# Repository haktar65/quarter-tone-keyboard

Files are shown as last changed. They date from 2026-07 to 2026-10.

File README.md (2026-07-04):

# Quarter-Tone Keyboard (QTKB)

A professional, stage-ready 24-tone-per-octave MIDI keyboard instrument with a custom quarter-tone layout, custom sensing, and a newly active synthesizer / semi-weighted action direction.

Public shorthand for GitHub-facing material: `QTKB`.

## Current Direction

- Layout: Kassel Principle with `61` standard keys + `61` quarter-tone keys
- Active feel target: Access Virus C / Fatar-family synth action feel
- Active mechanical category: synthesizer / semi-weighted with integrated aftertouch
- Sensors: one Hall sensor per key
- Phase 1: MIDI input device with USB-MIDI and 5-pin DIN

## Documentation Map

- `docs/Research.md`: active concept and design rationale
- `docs/BuildGuide.md`: active geometry, build, and prototyping document
- `docs/archive/SteinwayLike/`: archived piano-like intermediate branch, including former `Research.md`, `BuildGuide.md`, and MP5 reference notes
- `docs/CAD/`: OpenSCAD models and milestone geometry files

## Working Method

This repository is maintained so that design work can continue across fresh checkouts and new VS Code sessions without reconstructing context from scratch.

Operational rules:

- active design decisions belong in `docs/Research.md`
- active geometry, prototype rules, and build-facing tables belong in `docs/BuildGuide.md`
- public project framing and naming belong in `README.md`
- historical branches stay under `docs/archive/` and are used as evidence, not as the active default
- when terminology changes, active documents are updated first and archive material gets explicit mapping notes where needed

## AI Collaboration In VS Code

The project is developed with AI assistance inside VS Code.

Current collaboration pattern:

- the AI first reloads repository instructions and active documents before making design proposals
- active source priority is: `.github/copilot-instructions.md`, `README.md`, `docs/Research.md`, `docs/BuildGuide.md`, then relevant archive files only if needed
- geometry decisions are expected to be carried in OpenSCAD files under `docs/CAD/` when practical
- chat discussion should follow the language of the user's prompts, while repository documentation is kept in English
- when a decision changes, the AI is expected to update the relevant repository documents so later sessions inherit the result

Typical startup summary for a fresh session:

- project shorthand: `QTKB`
- active branch: synth / semi-weighted
- feel reference: Access Virus C / Fatar-style synth action
- layout principle: Kassel
- scope: `122` keys total
- active key families: `MWT`, `MST`, `QWT`, `QST`

## Active Technical Direction

The active workstream no longer uses the previously explored deep piano-like geometry as its target mechanism.

Current focus:

- shallower synth-action packaging
- integrated aftertouch as a first-class design feature
- consistent semi-weighted feel across all `122` keys
- quarter-tone integration without inheriting hammer-action geometry penalties

## Preserved Decisions

These decisions remain active across the branch change:

- quarter-tone layout based on the Kassel Principle
- Hall sensor sensing concept
- Teensy-based real-time front-end architecture
- stage-ready control concept including pitch bend and expression controls
- custom mechanical implementation rather than direct reuse of a stock 12-tone keybed

## Status

- [x] Kassel layout selected
- [x] Hall sensor concept selected
- [x] Archived the earlier `Steinway-like` branch under `docs/archive/SteinwayLike/`
- [x] Switched active direction to synth / semi-weighted action
- [ ] Geometrically lay out the active `MT` and `QT` keyboard families
- [ ] Build a one-octave test stand after the current `MT` / `QT` geometry pass

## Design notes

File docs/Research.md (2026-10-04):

# Quarter-Tone Keyboard (QTKB) – Research & Concept

## Project Goal

Build a high-quality, stage-ready quarter-tone keyboard as a MIDI input device for a professional player.

Public shorthand for GitHub-facing material: `QTKB`.

Fixed top-level goals:

- quarter-tone grid with `24` tones per octave
- high-quality, repeatable playing feel
- stage-ready controls and robust hardware
- custom mechanics, sensing, electronics, and firmware

## Current Mechanical Direction

Update June 2026: the active target category is now a synthesizer / semi-weighted action with integrated aftertouch.

Primary feel reference:

- Access Virus C
- Fatar-family synth keyboard feel

This replaces the previously explored deeper piano-like intermediate branch as the active target mechanism.

## Pianist-Critical Requirements

The following remain decisive for the active branch:

- professional appearance and tactile quality
- reliable touch distinction between main keys and quarter-tone keys
- controlled, musically usable aftertouch
- consistent response across the full keyboard
- no cheap controller feel

The active branch no longer optimizes around hammer-action-like proportions.

## Fixed Decisions That Remain Active

The branch change does not affect these decisions:

- layout principle: Kassel Principle
- scope: `61` main keys plus `61` quarter-tone keys
- key sensing: one Hall sensor per key
- aftertouch principle: travel into an elastomeric stop rather than FSR-based force sensing
- firmware split: real-time sensor front-end plus higher-level protocol/control layer
- stage focus: USB-MIDI, 5-pin DIN, performance controllers

## Mechanical Consequences of the New Direction

The active synth / semi-weighted branch implies:

- shallower action depth than the archived piano-like branch
- lower moving mass and less emphasis on long piano-style front lever arms
- a compact `MWT` planform with `50 mm` head length, `2 mm` lip, and `35 mm` tail length; the detailed, parameterized layout is held in `docs/CAD/Design/MasterLayout.csv`
- aftertouch must be designed into the base mechanism from the start
- pivot, travel, and return-force geometry must be re-derived from the synth-action category, not reused from the archived branch
- QT integration should be solved against the lighter action family, not against a deep hammer-style package

## Open Geometry Questions for the Active Branch

The following items now define the active research backlog:

- exact Access Virus C keybed family / concrete Fatar reference if identifiable
- main-key travel target for the synth branch
- black-key travel target for the synth branch
- pivot position and effective lever arms for a synth-like mechanism
- required pivot-axle capture in lever direction; the first print suggests the current wrap is too small, so a roughly `180 deg` capture should be tested as an active candidate where spacer washers already retain the axle laterally
- whether reducing the lever-side pivot support land to `5 mm` in the local washer zone remains mechanically acceptable inside the available `6.84 mm` width when that local contact region is executed in Tough Resin
- aftertouch onset travel, reserve travel, and target force range
- how the quarter-tone rows should be coupled to the shallower main-key geometry
- Hall sensor placement for the new shallower package

## Active Zero-Stop Guide Direction

Update September 2026: reject the radial splint / PTFE-tube guide near the
aftertouch buffer. The small-radius, family-specific bent splints make the
reaction-group construction unnecessarily difficult. The active prototype
instead uses the pivot axis and a guide at the rear zero stop as two separated
points of lateral `X` guidance.

- retain the shared pivot axis as the front guidance point
- place the brass guide splint and its PTFE guide at the rear zero-stop
	structure, about `75 mm` behind the pivot; it must be mechanically separate
	from the hard zero-stop contact function
- move the key's zero-stop lip slightly forward of the splint / guide line so
	the lip reaches its unobstructed stop face without interference from either
	the splint or the PTFE guide package

- use `5 x 4 mm` PTFE tube, compressed externally to an approximately
	`4 mm` in `X` by `6 mm` in `Y` oval section. The larger `Y` compliance accommodates the small
	kinematic migration at the rear guide while the narrow `X` direction provides
	lateral location
- use a `10 mm` axial PTFE bearing length as the first prototype value. It is
	intended for lateral control with the pivot as the second bearing point, not
	as a torsional bearing about `Y`
- keep the PTFE tube vertical in global `Z`. Tilt the straight brass splint
	by `4 deg` in its local `YZ` plane so it is approximately parallel to the
	tube around the middle of the QST stroke; the resulting endpoint mismatch is
	about `+/-3.6 deg` for the `7.17 deg` QST full-aftertouch rotation
- use a rounded and polished brass splint with `25 mm` free working length.
	At the QST governing case, a rear guide `75 mm` behind the pivot moves about
	`9.4 mm` in `Z` and `0.59 mm` in `Y` at `7.2 deg` full aftertouch. The
	`25 mm` free length preserves the `10 mm` PTFE engagement through that stroke
	with a practical end reserve; do not reduce it to `22 mm` until actual
	travel, tube deformation, and assembly tolerances are measured
- do not claim that this guide controls rotation about `Y`; validate remaining
	torsional freedom at the pivot and rear guide in the physical prototype

The first fabrication method is a straight, `4 deg`-tilted brass splint in a
printed rear guide block with a vertical PTFE tube. No radius-specific forming
jig is required. Prototype the oval PTFE section for friction, wear, `X` play,
and its actual available `Y` compliance before propagating the package across
all key families.

### Optional Aftertouch Stamp Catch Guide

An optional passive secondary guide may surround the key-side aftertouch stamp
with a shallow fixed tray. It is not part of the normal guiding system: pivot
and rear zero-stop guide remain authoritative.

- keep more than `0.5 mm` radial clearance around the stamp, so it remains
	non-contact in normal playing and normal aftertouch
- use only `4-6 mm` first-pass capture height, with generous lead-in radii and
	rounded stamp edges; do not turn it into a long sliding bearing
- its purpose is to catch exceptional side load from glissando or wide playing
	spans before the stamp is forced substantially sideways
- validate under full aftertouch and side load that first contact does not
	appreciably alter vertical end position, aftertouch force, or Hall signal

## Active Aftertouch Reaction Direction

Update August 2026: arrange the fixed reaction group horizontally in global
`XY` at the full-aftertouch position. The key-side stamp or contact face is
intentionally angled relative to the local key surface so that its face is also
horizontal at full aftertouch.

- the full-aftertouch reaction acts predominantly in global `Z`, rather than
	introducing a systematic `Y` component into the pivot and guide splint
- normal-travel to full-aftertouch motion produces only a small controlled
	tangential displacement in the felt contact layer; current first-pass values
	are about `0.10 mm` (`MWT`), `0.12 mm` (`MST`), `0.16-0.36 mm` (`QWT`), and
	`0.21-0.40 mm` (`QST`)
- use a smooth, continuous, limited-area contact face rather than a broad
	clamping interface; the felt absorbs the residual angle and displacement
- for FDM prototype stamps, print upright with the load-bearing contact face
	horizontal and uppermost. The vertical reaction load then acts principally
	in compression through the layer stack, and no support touches the functional
	contact face

## Electronics and Firmware Direction

The action-family switch does not change the preferred electronics architecture:

- Teensy remains the real-time sensor front-end
- Hall sensors remain the key-position sensing basis
- selected Hall sensor: `Allegro A1324LUA-T`, a linear ratiometric analog Hall sensor in the `TO-92S` package; use one sensor per key
- use the continuous analog position signal for velocity threshold timing and aftertouch evaluation
- multiplexed analog acquisition remains acceptable
- optional second processor / protocol back-end remains open

## Active Multiplexed Scan and Decoupling Direction

Update September 2026: the initial electronics prototype is a complete grouped
Hall-sensor front end, rather than a single sensor on an ideal short connection.

- use `8 x CD74HC4067` analog multiplexers, each with one separate Teensy ADC
	input; the four mux address lines are shared, giving eight simultaneous values
	per address position and capacity for `128` inputs
- treat the eight mux outputs at a common address as an atomic acquisition
	block. Read block `n`, change the common address immediately to `n + 1`, then
	process or queue block `n` while the next block settles
- start with about `90 us` address settling. This is intentionally conservative
	and should cover the selected Hall output, harness, mux, and ADC acquisition
	path; raw ADC data determines whether it can be reduced
- do not add Hall-output capacitors initially. They are a dynamic signal filter
	and can worsen address-switch settling; they require a demonstrated noise
	benefit before becoming part of the design
- retain minimal group-level supply decoupling independently of the chosen mux
	settling time: `10 uF` at both physical ends of a group, plus `100 nF` at the
	mux/group supply injection and at the far end when the harness is long
- do not provision `100 nF` at every sensor initially. Add sensor-local parts
	only if a full-group test shows a local supply-noise mechanism which the
	group-level capacitors do not suppress
- acquire and transmit data asynchronously from the periodic scan. USB-MIDI,
	debug logs, and a future protocol back-end must consume buffered events rather
	than introduce timing jitter into address-block acquisition

The important distinction is between selected-channel signal settling and
supply-rail decoupling. A `90 us` wait may be more than sufficient for the
former, but does not by itself lower the local VCC/GND impedance during digital
switching or key motion. The first group test must compare `10`, `20`, `40`,
`60`, and `90 us` waits while recording raw rest noise, address residue,
repeatability, travel headroom, and supply ripple. This measurement, using the
intended cable length and scan load, decides both the final wait time and
whether additional ceramic capacitors are justified.

## Active Hall Crosstalk Assessment

Current working concern:

- the closest known intra-group Hall-sensor case is inside `QWT`, especially the `E/F` neighbor pair
- the current rough geometry uses cylindrical magnets `4 x 3 mm`
- the active own-magnet operating region is expected around `2-3 mm` from its own Hall sensor in the relevant near-contact region
- the same local pair can place a neighbor magnet at about `15 mm` lateral offset in `X`
- the rest position of a non-pressed neighboring key is currently assumed to keep its own magnet about `12-13 mm` above its own Hall sensor in `Z`

Current prototype observation (August 2026):

- in the tested sensor / magnet arrangement, a lateral `X` offset of `10 mm` produced no practically visible neighbor response; this is stronger evidence than the earlier conservative dipole estimate, but remains geometry-specific until confirmed in the final lever layout
- the observed useful own-magnet distance span is about `8 mm`; calibrate each key's rest value and full-travel value individually rather than requiring identical absolute sensor placement across all keys
- steel hardware near a sensor can redirect the own-magnet field and must not be treated as equivalent to a laterally offset neighbor magnet; brass remains preferred for the adjustable guide splints

First-order interpretation:

- the relevant magnetic coupling should be treated with a dipole-like first estimate, so field influence falls roughly with `1/r^3`, not with `1/r^2`
- for the actively pressed key, a `15 mm` lateral neighbor is therefore expected to be small compared with the own-magnet signal once the own magnet is only about `2-3 mm` from its own sensor
- for the non-pressed neighboring key, the situation is less favorable because the comparison is then no longer `2-3 mm` versus `15 mm`, but roughly `12-13 mm` versus `15 mm`
- this means a visible neighbor-induced offset in the idle or upper-stroke signal is plausible even if the main active stroke remains dominated by the own magnet

Current risk interpretation:

- the primary risk is not currently seen in the main stroke of the pressed key
- the more credible risk is crosstalk in the upper signal region of the non-pressed neighbor, and possibly in the later expression / aftertouch interpretation window
- if no activity is derived from the rest-near zone, crosstalk there is largely irrelevant from a musical-control perspective
- a moderate, systematic influence in the expression or aftertouch region is considered more acceptable than ambiguity in the main attack / velocity region

Current project interpretation:

- `QWT E/F` should be treated as the worst-case crosstalk pair for prototype verification
- the present expectation is that the main stroke may still remain usable without mechanical redesign even if the upper signal region shows measurable neighbor influence
- if the crosstalk is mostly systematic and appears mainly in expression / aftertouch, later compensation in signal processing remains a viable option
- compensation should only be considered after direct measurement of the worst-case pair; it should not be assumed as a substitute for first-order geometric sanity

## Active Zero-Stop Damping Decision

Update June 2026:

- the rear zero stop remains a hard geometric rest-height reference, not a soft free-working stop
- acoustic damping at the zero stop may be added, but only as a thin, strongly constrained working layer in front of a hard rail
- preferred first damping forms are a small solid profile or strip in `TPU` or `PORON`, not a hollow profile
- hollow profiles remain possible as acoustic experiments, but they are not the preferred reference-defining construction because they are more prone to hysteresis, temperature sensitivity, and rest-height drift
- shrink tube may still be used around separate trim-mass pieces as a pragmatic noise-reduction measure, but it should not be shrunk directly on the mounted `ASA` lever and should not define the zero-stop geometry

## Archive Boundary

The previously explored piano-like intermediate branch is now preserved only as an archive snapshot under:

- `docs/archive/SteinwayLike/Research.md`
- `docs/archive/SteinwayLike/BuildGuide.md`
- `docs/archive/SteinwayLike/MP5GeometryReference.md`
- `docs/archive/SteinwayLike/SteinwayLikeArchive.md`

Those files remain useful as historical design context, but they no longer define the active geometry target.

Historical archive terminology may still use earlier internal abbreviations.

## Immediate Next Steps

- identify the best usable Access Virus C / Fatar reference data
- define the active coordinate system for the synth branch
- establish first main-key synth geometry targets
- derive quarter-tone packaging rules from the new shallow action category
- test whether a roughly `180 deg` pivot wrap gives enough directional stiffness in the lever while remaining practical with the washer-retained axle concept
- test whether a local reduction of the lever-side pivot support land to `5 mm` in the washer zone is still stiff enough when printed in Tough Resin
- measure the `QWT E/F` Hall crosstalk worst case and separate main-stroke relevance from expression / aftertouch relevance before changing magnet polarity or local sensor topology
- build a single-key prototype around the synth-action assumptions

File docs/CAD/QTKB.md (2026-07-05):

# QTKB STEP Exports

The STEP files in this folder are currently direct exports from the active QTKB working drawing.

At this stage they should be treated as working geometry snapshots, not as a curated release set.
The source drawing still contains parallel design experiments, intermediate variants, and naming that reflects the current TurboCAD work structure rather than a final part taxonomy.
In particular, `QTKB.stp` should currently be expected to change substantially over time because it is the direct export of the active working map.

Because of that, the exported STEP files are intentionally not documented one by one yet.
Adding detailed per-file notes at this point would create documentation overhead without much long-term value.

Current meaning of the exported files:

- `QTKB.stp`: full export of the current working drawing; this file may change strongly and often because the underlying working map is still in active exploratory use
- `QTKB-blocks/`: per-block STEP exports generated from the same working drawing; these are also still provisional, but the individual block exports are expected to stabilize earlier than the full drawing export

Once the design stabilizes, the STEP exports will be cleaned up, grouped more deliberately, and documented individually.

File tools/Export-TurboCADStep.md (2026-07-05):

# Export-TurboCADStep.vbs

Small helper script for exporting one TurboCAD `.tcw` drawing and its blocks as STEP files.

## What it does

- opens the source `.tcw` through TurboCAD COM automation
- creates a temporary working copy inside `_tcw-temp`
- exports the full drawing as `<project>.stp`
- clears the working drawing, inserts one block, and exports that state as one STEP file per block
- writes block STEP files into `<project>-blocks`

## Requirements

- Windows
- TurboCAD 2020 installed locally
- TurboCAD COM automation available as `TurboCAD.Application`
- the source drawing should contain 3D geometry that TurboCAD can actually write to STEP

Pure 2D blocks may not produce useful STEP output.

## Usage

```cmd
cscript //nologo Export-TurboCADStep.vbs <input.tcw> <output-dir> [visible]
```

Example:

```cmd
cscript //nologo Export-TurboCADStep.vbs "C:\path\to\drawing.tcw" "C:\path\to\export" True
```

## Parameters

- `input.tcw`: source TurboCAD file
- `output-dir`: target folder for the exported STEP files
- `visible`: optional Boolean, usually `True` or `False`; default is `True`

## Output layout

```text
export/
├── <project>.stp
├── <project>-blocks/
│   ├── BlockA.stp
│   ├── BlockB.stp
│   └── ...
└── _tcw-temp/
    └── <project>-working-<timestamp>.tcw
```

## Current behavior

- the script aborts immediately if any `tcw27.exe` process is already running
- existing STEP files with the same name are overwritten
- block names are sanitized for Windows file names
- the script prints `Writing: ...` for each STEP file it exports
- the script attempts to delete the temporary working copy at the end

## Notes

- the block export path currently uses the block name in `AddBlockInsertion`
- runtime errors are intentionally not masked; VBScript should stop directly on the failing line
- after `SaveCopyAs`, the script still checks whether the STEP file was actually written

## First troubleshooting steps

- run once with `True` as the third argument so you can watch TurboCAD during the export
- if the script aborts on a specific line, use that exact VBScript line number as the primary debugging anchor
- test the same drawing manually in TurboCAD with a normal STEP export to confirm that the geometry is STEP-compatible

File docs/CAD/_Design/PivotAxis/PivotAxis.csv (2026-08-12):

Pivot Axis Parameters
LengthX	WidthY	MountHeight	BrassShaftRadius	WashersRadius	WashersThickness	K20Z
165.2	20	3	2	6	1	-20
Geometry Parameters
Outer Slope	Inner Slope	WT Width C-E	WT Width F-B	ST Width
10	40	14.6	13.475	13.5
Segmentation
C		C#		D		D#		E		F		F#		G		G#		A		A#		B
0	7.3	14.6	21.35	28.1	35.4	42.7	49.45	56.2	63.5	70.8	77.5375	84.275	91.025	97.775	104.512	111.25	118	124.75	131.488	138.225	144.975	151.725	158.463	165.2

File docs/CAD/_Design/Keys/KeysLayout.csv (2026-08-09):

Common Dimensions
Parameters	OctaveWidth	Air Gap X	Air Gap Y	Rounding	PivotAxisY	PivotAxisZ
	165.2	1	1	1	210	-12
Calculations
MWT Dimensions
Parameters	Head Length	Tail Length	Height	Lip Length	Lip Height
	50	35	14	2	2
Calculations	Head Width	Rear Width C-E	Read Width F-B	BackFaceSlop
	22.6	13.6	12.475	85.7108
MWT Keys Configuration Table
	Head Start X	Tail Start X	Tail Width
C	0	0	13.6
D	23.6	28.1	13.6
E	47.2	56.2	13.6
F	70.8	70.8	12.475
G	94.4	97.775	12.475
A	118	124.75	12.475
B	141.6	151.725	12.475
MST Dimensions
Parameters	Start Y	Length	Width	Key Height	Body Height	Top Slope	Side Bevel	Front Bevel
	51	64	12.5	12	10	1	2.38594	11.7683
Calculations	BackFaceSlop
	82.8008
MST Keys Configuration Table
	Start X
C#	14.6
D#	42.7
F#	84.275
G#	111.25
A#	138.225
QWT Dimensions
Parameters	Start Y	Length	Key Height	Body Height	Side Bevel	Front Bevel
	86	84	12	10	18.4349	14.0362
Calculations
QWT Keys Configuration Table
	Start X	Width
Cq	0	13.6
Dq	28.1	13.6
Eq	56.2	13.6
Fq	70.8	12.475
Gq	97.775	12.475
Aq	124.75	12.475
Bq	151.725	12.475
QST Dimensions
Parameters	Start Y	Length	Key Height	Body Height	Side Bevel	Front Bevel
	116	54	12	10	18.4349	14.0362
Calculations	Start Z
	11
QST Keys Configuration Table
	Start X	Width
C#q	14.6	12.5
D#q	42.7	12.5
F#q	84.275	12.5
G#q	111.25	12.5
A#q	138.225	12.5

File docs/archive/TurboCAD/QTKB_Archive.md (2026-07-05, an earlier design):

# QTKB Archived STEP Exports

The STEP files covered by this note are archive exports only.

They represent drawings and geometry snapshots that are no longer part of the active QTKB workstream, but may still be worth keeping for selective reuse, comparison, or extraction of isolated ideas.

These files should not be treated as active design defaults.
Active geometry and active branch decisions remain defined by:

- `docs/Research.md`
- `docs/BuildGuide.md`
- the current active CAD work under `QTKB.stp` and `QTKB-blocks/`

Current meaning of the archived files:

- `QTKB_Archive.stp`: full archived STEP export of drawings that are no longer needed in the active workstream
- `QTKB_Archive-blocks/`: archived per-block STEP exports kept only for possible later reuse of individual geometry fragments

Usage rule:

- reuse material from this archive deliberately, not implicitly
- when reusing geometry, re-check it against the current synth / semi-weighted branch assumptions before bringing it back into active CAD
- do not interpret archived naming, dimensions, or package logic as current defaults

This archive is intentionally retained as a parts and ideas reservoir, not as a maintained parallel design branch.

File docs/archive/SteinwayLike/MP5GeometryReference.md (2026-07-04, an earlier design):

# Kawai MP5 Geometry Reference

> **Archive role (June 2026):** This MP5 note now belongs to the archived `Steinway-like` branch. It remains useful as a proportional reference for the earlier piano-like geometry study, but it is no longer the active target direction for the keyboard layout.

This note collects the geometry-related information currently available for the Kawai MP5 and separates public source-backed facts from project-side geometric inference.

## 1. Publicly Confirmed MP5 Data

The following items could be confirmed from Kawai's public MP5 archive/specification material:

- Keyboard action: `88 weighted keys, Advanced Hammer Action IV-E with AR technology`
- Overall dimensions: `1356 x 340 x 172 mm` (`W x D x H`)
- Weight: `20.5 kg`

These are useful packaging anchors, but they do **not** include an internal pivot drawing or a service-level action section with exact key-axis coordinates.

## 2. Public Geometry That Could Not Be Confirmed Directly

The following internal action data has **not** been found in a public Kawai source during this research pass:

- exact white-key pivot coordinates relative to the front edge
- exact pivot height relative to the white-key top surface
- exact white-key overall length or hammer-stick length
- exact black-key reference point and black-key lever arm
- exact guide-pin or balance-pin coordinates
- exact MP5 service drawing for the AHA IV-E action

Therefore, any concrete pivot coordinate stated below must be treated as a **project reference estimate**, not as a factory-proven MP5 CAD value.

## 3. Current Project Reference Geometry Derived from the MP5 Comparison

For the current keyboard project, the MP5 comparison was condensed into the following working reference geometry for the normal key row:

- White-key front reference point at rest: `O = (0, 0)`
- Main-key pivot axis: `Y = 210.0 mm`, `Z = -24.0 mm`
- Interpretation: pivot about `210 mm` behind the white-key front edge and about `24 mm` below the white-key top reference surface

This reference is already the active baseline in the project documentation and is treated as a plausible MP5-like proportion rather than a measured Kawai internal dimension.

## 4. Derived Lever Arms and Motion References

Using the current project reference pivot above, the following effective lever arms are in use:

- White key front lever arm: `210.0 mm`
- Black key front reference plane: `Y = 53.5 mm`
- Effective black-key front lever arm: `210.0 - 53.5 = 156.5 mm`

Associated geometric motion references currently used in the project:

- White-key front travel: `10.8 mm`
- Black-key front travel: `10.0 mm`
- White-key bottom-stop rotation: `asin(10.8 / 210.0) = 2.95 deg`
- Black-key bottom-stop rotation: `asin(10.0 / 156.5) = 3.66 deg`

These values are not public MP5 measurements. They are the current project-side geometric interpretation of an MP5-like normal-key proportion.

## 5. Confidence and Use Rule

Current confidence split:

- **High confidence:** the MP5 uses the `AHA IV-E` action with AR technology, and the external instrument envelope is `1356 x 340 x 172 mm`
- **Medium confidence:** a pivot around `Y = 210 mm` from the white-key front edge is a realistic MP5-like proportion
- **Medium confidence:** a pivot around `Z = -24 mm` relative to white-key top reference is a realistic MP5-like vertical placement
- **Low confidence as a factory claim:** `Y = 210 mm`, `Z = -24 mm` as the literal internal Kawai MP5 production coordinate

Design rule for this project: use `Y = 210 mm`, `Z = -24 mm` as the working MP5-style reference geometry unless direct measurement from a real MP5 action or a service drawing becomes available.

## 6. Source Notes

Public sources checked during this pass:

- Kawai MP5 archive/specification page
- Kawai MP5 owner's manual PDF
- public manual mirrors and general web results

Outcome of the source pass:

- official/public sources were sufficient to confirm the action family and external instrument dimensions
- official/public sources were **not** sufficient to confirm an internal pivot drawing or an exact service-level coordinate set

## 7. Practical Consequence for Further Work

If tighter fidelity to the MP5 action is required, one of the following would be needed:

- direct measurement on a real MP5 keybed
- a genuine service manual with mechanical drawings
- teardown photography with a known dimensional reference in the same plane

Until then, the project should treat the MP5 comparison primarily as a **proportional reference**, not as a fully known reverse-engineered mechanism.

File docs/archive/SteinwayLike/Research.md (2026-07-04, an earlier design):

# Quarter-Tone Keyboard – Research & Concept

> **Update (June 2026):** The previously explored piano-like geometry branch is now archived as a `Steinway-like` reference snapshot in `SteinwayLikeArchive.md`. The active workstream switches to a synthesizer / semi-weighted layout direction with Access Virus C as the primary feel reference and Fatar keyboard feel as the family anchor.

> **Archived naming note:** `VT` is the older archive label for what the active branch now groups under `QT`. This archive generally distinguishes `main keys` and `VT keys`, not the active four-family set `MWT`, `MST`, `QWT`, `QST`.

## Project Goal

Build a high-quality, stage-ready quarter-tone keyboard as a MIDI input device for a professional jazz pianist. Requirements:

- Quarter-tone grid (24 tones per octave)
- High-quality, demanding playability (level: Gaspard de la Nuit)
- Impressionistic playing style, improvisation, original compositions
- Stage-ready: Pitchbend, volume control, optional further modulation controllers
- Phase 1: MIDI input device (USB-MIDI and 5-pin DIN)
- Manufacturing: FDM/SLA printing, woodworking, custom electronics/firmware

### 0.1 Requirements from the Pianist's Perspective

These requirements are critical for all mechanical decisions and take priority over manufacturing convenience.

#### Must Criteria

- Professional appearance in look, feel and playing response
- Standard piano technique must not be compromised; the keyboard must be playable from classical technique
- White keys receive original piano key covers as the primary visual and tactile surface
- Black keys receive a high-quality top layer; intended: ABS-like Tough Resin
- Quarter-tone keys must be reliably distinguishable by touch, without looking cheap or provisional
- Consistent, reproducible key action across the entire keyboard

#### Should Criteria

- Quarter-tone keys receive deliberate haptic differentiation from the main keys
- FDM surfaces can be intentionally used as a tactile feature, provided the result is controlled, pleasant, and high-quality
- The keyboard should feel like a serious instrument rather than a controller prototype
- A high-quality synth / semi-weighted action with integrated aftertouch is now preferred over a hammer-action category
- Target playing feel: clearly closer to a high-quality synthesizer keyboard than to weighted stage or piano action
- Reference: Access Virus C with Fatar keyboard feel as the primary direction anchor

#### Not Acceptable

- Stub-key solutions at the expense of pianistic ergonomics
- Visibly improvised surfaces at primary contact points
- Inconsistent friction, lateral wobble, or strongly varying key moments
- Quarter-tone keys that are only visually distinguishable but cannot be reliably identified by touch

#### Immediate Mechanical Consequences

- Pivot point, key mass, and counterweights must not be chosen primarily for packaging or sensor placement, but for playing feel
- Key surfaces are part of the function, not merely cosmetic
- Quarter-tone keys need a defined tactile identity; treating all keys the same is not necessarily optimal here
- The previously explored piano-like / `Steinway-like` branch is archived and no longer defines the active target mechanism
- Simple unweighted levers are acceptable only as an early functional prototype, not as the target mechanism; the active target remains controlled synth / semi-weighted action

### 0.2 Mechanical Target Range

#### Target Playing Feel (updated May 2026)

- Category: **Synthesizer / Semi-Weighted** – not stage piano or hammer action
- Reference: Access Virus C as the preferred feel target; Fatar keyboard feel as the relevant action family
- Hammer action excluded: too heavy, too deep, wrong category for this instrument
- Target: consistent semi-weighted feel across all 122 keys; quarter-tone keys intentionally lighter but controlled

Weight estimate for 122 keys semi-weighted: ~4–7 kg for key mechanism alone. Significantly lighter than a hammer action variant.

#### Implications

- Not a pure geometry solution, but a controlled mass and lever mechanism
- Front weight, return force, and friction level must be deliberately calibrated
- The quarter-tone mechanism must not significantly degrade the feel of the main keys

#### Architecture Option: Donor Mechanism Based on Fatar

A seriously considered option was purchasing two weighted Fatar keyboards as mechanical donors.

Advantages:
- Defined, musically usable base mechanism
- Existing weights, bearings, and key kinematics
- Significantly lower risk in achieving professional playing feel

Disadvantages:
- Substantial modification work required for the Kassel quarter-tone layout
- Donor mechanism designed for 12-tone geometry, not for a second and third key plane
- Integration of quarter-tone keys behind the pivot remains a custom design regardless
- Geometric degrees of freedom may be constrained by the donor mechanism

**Decision (May 2026): Full custom build**

Purchasing a ready-made keybed was evaluated and rejected. Reasons:
- White key tails occupy exactly the space needed for Keybed 2 and VT actuation
- Any deviation from original geometry requires deep intervention in a design not intended for it
- With the Hall sensor concept (see Section 4.2), custom sensing is simpler than reverse-engineering a keybed
- Custom build gives full freedom in pivot position, lever geometry, weighting, and cutouts

Next step: test bench with a single key (main key + VT key) before any further purchases.

---

## 1. Concept: Keyboard Layout

### 1.1 Core Problem

A quarter-tone keyboard must make 24 tones per octave accessible – twice as many as a standard keyboard. Several established layout approaches exist.

### 1.2 Decided Layout: Kassel Principle (Organ St. Martin, Kassel)

**Reference:** New organ of the Martinskirche Kassel – single-manual quarter-tone keyboard with an extended black-key principle.

#### Principle: Two rows of raised keys behind each standard key row

The octave is organized into **three depth planes** and **three height planes**:

| Key type | Position (depth) | Height | Pitch step |
|---|---|---|---|
| White keys | front | base plane (0) | C D E F G A B |
| Black keys (1st row) | middle | +12 mm (standard) | C# D# F# G# A# |
| Whole steps +¼ | behind white keys | +12 mm (= black key height) | C↑ D↑ E↑ F↑ G↑ A↑ B↑ |
| Half steps +¼ | behind black keys | +12 mm + Δ (further raised) | C#↑ D#↑ F#↑ G#↑ A#↑ |

**In detail:**
- **Whole steps + ¼ tone** (e.g. C+¼): sit behind the white keys at black-key height. For the player they are like a second row of black keys, but more accessible in width.
- **Half steps + ¼ tone** (e.g. C#+¼): sit behind the black keys, raised by the same increment again.

#### Playing Concept
- Piano technique remains fully intact – standard repertoire playable without adaptation
- Quarter tones are reachable by reaching backward/upward with the finger, similar to reaching far back on the black keys
- Intuitive assignment: every key has its quarter-tone neighbor directly behind it
- No remapping of the tonal space required

---

## 2. Dimensions (Research State)

From `Tastatur.txt` and standard sources:

| Component | Dimension (mm) | Note |
|---|---|---|
| Octave width | 165.0 | 7 white keys |
| White key width (head) | 23.6 | front section |
| White key length (visible) | 150.0 | to housing |
| Black key width (base) | 12.5 | top ~11.5 mm |
| Black key length | 95.0 | visible |
| Black key height | 12.0 | above white level |
| Key travel (white, front) | 10.8 | |
| Key travel (black) | 10.0 | |
| Pivot point | 180–250 | from front end |

**Quarter-tone keys – geometric constraints:**

- Width: ≤ black key width (≤ 12.5 mm), must fit in the same lateral space
- Length: as long as reachable without blocking black keys; likely 30–50 mm visible
- Height whole steps+¼: equal to black key height = +12 mm above white
- Height half steps+¼: black key height + Δ (Δ = step height white→black ≈ 12 mm) → ~+24 mm above white
- Travel: likely 8–10 mm (like black keys)
- Pivot: approximately 180–250 mm behind the front end of the white key, same as main keys

---

## 3. MIDI Implementation

### 3.1 MIDI 1.0 – Microtonality

Standard MIDI knows only 128 semitones. Several approaches exist for microtonality:

| Method | Description | Drawback |
|---|---|---|
| **Pitch Bend per note** | Each key sends Note + individual Pitch Bend | Only 1 bend per channel → limited polyphony |
| **MPE** (MIDI Polyphonic Expression) | Each note on its own channel (1–15) | Max. 15 simultaneous notes, broad synth support |
| **MIDI 2.0** | Per-note pitch with full resolution | Still limited synth support (2024–2026) |
| **Multi-channel mapping** | Quarter-tone keys on separate channel with global bend | Simple but inflexible |

> **Decision (May 2026): 24-tone mapping – no MPE.**
> The 122 keys (61 base + 61 VT) are mapped to MIDI notes 0–121. Each note has a defined frequency via Scala tuning table (.scl) in the synthesizer. No pitch bend trick, no MPE. Standard MIDI Note On/Off + Velocity. Aftertouch as Channel Aftertouch or CC.
>
> **Target software:** Logic Pro (native Scala support) and later SuperCollider (tuning classes, later OSC for continuous-board extension).
>
> MPE is entirely dropped – it was only needed to enable per-note pitch bend, which is not required with the 24-tone mapping approach.

### 3.2 Pitch Bend Resolution

Standard: ±2 semitones (200 cents) at 14-bit resolution → ~0.024 cents resolution. One quarter tone = 50 cents → easily representable.

### 3.3 Interfaces

- **USB-MIDI** (primary, class-compliant, no driver required)
- **5-pin DIN MIDI Out** (for older stage synthesizers)
- Optional: **TRS-MIDI** (3.5 mm, Type A or B)

---

## 4. Electronics

### 4.1 Microcontroller Candidates

| Controller | Advantages | Disadvantages |
|---|---|---|
| **Teensy 4.1** | Native USB-MIDI, very fast (600 MHz), extensive MIDI library, proven in DIY keyboards | Proprietary, more expensive (~€30) |
| **Raspberry Pi Pico (RP2040)** | Cheap (~€4), PIO for precise timing, USB-MIDI via TinyUSB | Fewer ready-made MIDI libraries |
| **Raspberry Pi Pico 2 (RP2350)** | Newer version, more RAM/Flash | Same limitations |
| **STM32F4xx** | Very common in professional MIDI hardware | More complex setup |

> **Recommendation:** Teensy 4.1 for quick start and proven MIDI libraries. For large key counts (>88 keys) possibly Raspberry Pi Pico as distributed architecture with I²C/SPI multiplexing.

### 4.2 Key Sensing – Decided Concept: Hall Effect

#### Basic Principle

**One linear Hall effect sensor per key**, permanent magnet fixed to the key. The sensor continuously outputs a DC voltage proportional to field strength – no pulse, no switch.

- **Velocity:** Teensy measures time between two voltage thresholds (software side, no second sensor)
- **Aftertouch:** the last 1–2 mm of travel past the main strike point (into elastomer stop) are measured directly
- **No FSR needed** – one sensor handles all three functions

#### Recommended Components

| Sensor | Type | Advantage |
|---|---|---|
| SS49E / SS495A | linear, analog | cheap, 5 V, readily available |
| A1324 / A1325 | linear, analog | more precise, ratiometric |
| DRV5055 | linear, analog | very small (SOT-23), Texas Instruments |

Small neodymium magnet (3×2 mm or 4×2 mm) on/under the key; Hall sensor on its own PCB in the frame.

#### Mounting Orientation

| Key group | Sensor position | Magnet position | Signal direction |
|---|---|---|---|
| Main keys | PCB at frame floor | underside of key tail | voltage drops when pressed |
| VT keys | PCB at frame ceiling | top of VT key | voltage rises when pressed (`value = MAX - raw`) |

VT keys have no space for sensor and stop below → PCB sits at the top of the frame, directly above the playing zone. Simple firmware inversion.

#### Aftertouch: Elastomer Stop instead of FSR

At the end of normal travel, the key presses into an **SLA-printed stop made of Flexible/Elastic Resin** (~Shore A 40–60). This yields 1–2 mm – the Hall sensor measures this travel directly.

- **No separate FSR, no additional wiring**
- Stop geometry (wall thickness, cavity) determines force–travel curve → iterate on test bench
- Suitable resins: Formlabs Flexible 80A / Elastic 50A, Phrozen Aqua Flexible, Liqcreate Flexible X
- Firmware: voltage range below `V_bottom_mechanical` is mapped to Aftertouch 0–127

#### Calibration (service / setup sequence, not continuous in-play learning)

Current preferred direction is a guided **three-point calibration per key**:

1. `0` = rest position
2. `pressed` = user-defined weighted press point
3. `aftertouch` = defined aftertouch / end-zone point

Role split:

- **Teensy** measures and delivers the raw values / stable averages
- **ESP32** or equivalent system controller leads the sequence, prompts the user, and stores / commits the resulting parameters

Important design intent:

- this is a setup / service calibration, not a continuous adaptation to the player's touch
- optional slow zero-point tracking in true rest state is acceptable
- the full `pressed` and `aftertouch` points should not be re-learned automatically during normal playing

#### Electronics

122 analog channels → 8× CD74HC4067 (16:1 mux) → 8 analog pins on Teensy 4.1. Teensy 4.1 has 18 analog pins – sufficient with reserve. Current packaging preference is to keep Hall sensor wiring local and distribute the mux boards close to the sensor groups where possible. Scan rate at 600 MHz: all 122 channels in under 1 ms.

### 4.3 Key Matrix & Multiplexing

With 61 base keys (5 octaves + 1 C) and doubled layout → 122 analog Hall channels:
- 8× `CD74HC4067` is sufficient for the full keyboard (`128` available channels for `122` sensors)
- preferred topology: shared `S0-S3` select lines, one dedicated analog output per mux to the Teensy ADC inputs
- enable lines are only required if several muxes are intentionally bussed onto one analog input; this is not the preferred baseline
- target: full scan cycle < `1 ms` for latency-free velocity measurement

### 4.4 Controllers (Pitchbend, Volume, etc.)

- 2× Alps RK09D potentiometer or endless encoder for pitchbend wheel
- 1× slider or pot for volume/expression
- Optional buttons for octave shift, program change, etc.
- Current preferred system split: these slow controls should be measured by the second controller, not by the Teensy real-time sensor front-end
- Preferred implementation quality: second controller + external ADC for `2-4` expression / pedal channels

---

## 5. Mechanics & Structure

### 5.1 Key Mechanism – Decided Concept

#### Basic Principle: Long Lever with Weight and Tension Spring

- Total lever length: ~230 mm (50 mm playing zone + 102 mm under black keys + ~80 mm tail)
- Pivot: captured 4 mm steel pin, one pin per half-octave (~82 mm)
- Return: tension spring near pivot (wire Ø0.3 mm, k ≈ 0.12 N/mm)
- Weight: ~15–20 g lead in key tail, press-fit
- Key blank material: **Polymaker PolyLite ASA** (Tg ~108°C, low warp, UV-resistant)

#### Target Forces

| Parameter | Target value |
|---|---|
| Downweight (strike weight) | ~45–50 g at finger point |
| Upweight (return force) | ~25–35 g |
| Aftertouch onset | ~50 g (= 0.5 N) |
| Aftertouch end | ~100 g (= 1.0 N) |
| Aftertouch travel | 3–4 mm (clavichord reference) |

#### Pivot Bearing

- **Pivot bearing:** 4 mm steel pin continuous, key hooked in via hook-nut geometry
- Hook-nut in ASA runs directly on steel pin, silicone oil applied once at assembly
- **Front guide:** HSS nail drill Ø2 mm (~28 mm long), bonded into Tough Resin frame (Loctite 638 or press fit), PTFE tube Ø4/2 mm as bushing in key
- Guide slot in key: elongated hole ~2.2 × 8 mm (allows travel without binding)
- **Side guidance:** integral partition walls in SLA frame, gap ~0.15–0.2 mm

#### Modular Frame

- Unit per **half-octave** (~82 mm) = C–E and F–B separate
- Fits in SLA print bed (120 mm width)
- Split at E/F: natural gap in black key row, shared bearing block = central support against pin deflection
- Supports at octave boundaries: **aluminium square tube 10×10×1 mm** as structural insert in printed ASA/Tough Resin shell
- Frame Tough Resin (SLA): precise, with integral pivot web and partition walls

#### End Stop and Aftertouch Buffer

- Front guide pin carries a slip-on **silicone O-ring** (Shore A 30–40, cord Ø3–4 mm)
- O-ring yields 3–4 mm travel at ~1 N end force → aftertouch zone
- Below that: **felt pad on hard substrate** as firm end stop (no click noise)
- Hall sensor just behind the guide pin (15–20 mm from front end) → measures full travel directly

**Option B: SLA-printed slotted hollow cylinder (Formlabs Elastic 50A)**
- Hollow cylinder with closed top and bottom rings + 4 axial rounded slots in middle zone
- Sits freely on frame floor in centering recess, key presses from above (no captive pocket)
- Closed end rings distribute stress at slot terminations → far better fatigue life than through-slots
- Hard stop ring (Standard Resin) on top limits travel to hub_max = 3 mm
- Optional outer sleeve with ~9.6 mm bore creates progressive force onset at near-full travel
- Parametric SCAD model: `docs/CAD/aftertouch_puffer_schlitz.scad`
- Estimated force: ~1.7 N at 3 mm with default parameters; tunable via slot depth/width

**Option C (preferred for prototype and long-term): EPDM commercial profiles**
- No printing required; purchased by the metre; trivially serviceable
- **Guide pin is independent** of the buffer — buffer sits on frame floor, key has flat contact surface
- Guide pin material: **hardened steel Ø2 mm** (dental/nail drill bits, already ordered)
  - Martensitic stainless steel; may be remanently magnetised by key magnet
  - Mitigation: minimum **25 mm distance** between pin and Hall sensor centre
  - At 25 mm: stray field < 0.3 mT → < 1.5 mV offset at sensor, negligible
  - Ceramic (ZrO₂) ruled out: brittle under bending loads from glissandi → fracture risk
  - CFK ruled out: fibre splitting at PTFE sliding surface (experience from aeromodelling)
  - Steel at 25 mm spacing is the final solution, not just a prototype choice
- Hall sensor mounted **directly below the buffer** in the frame floor:
  - EPDM is non-magnetic; field passes through without distortion
  - Buffer contact point = Aftertouch zero point, mechanically and sensorially identical
  - Rest position: magnet far → low field; EPDM contact: magnet ~2 mm above sensor → Aftertouch zone begins; full travel: hard stop → maximum value

**Current prototype stack (main keys, May 2026): felt + PORON with Kapton isolation**
- Hall sensor sits in front frame pocket (about 8 mm deep region)
- Sensor top is covered by **2-layer Kapton tape** (50–100 um each), then 1.2 mm dense piano felt
- No FR4 cover plate in baseline build (height budget and precision geometry control)
- Mechanical load path is carried by surrounding frame geometry, not by sensor package
- Behind front end-stop zone: PORON strip, 4 mm thick and 4 mm wide, as felt/PORON/felt sandwich
- Initial PORON height: flush with end-stop level; tuning option: lower PORON by 1.0 mm
- Target feel: clear strike point + additional ~2 mm controlled aftertouch travel

**Option C1 – EPDM D-profile (solid rubber, hollow cross-section)**
- D-profile 9 × 10 mm (height × width), wall ~1.5 mm, Shore A 60
- Cut to 12 mm per key; flat base for bonding (contact adhesive or cold vulcanising)
- 2 mm compression = 22 % → force ~1.5–2.5 N; clear tactile onset from hollow collapse
- Best choice for a clearly perceptible aftertouch entry point
- Search term: *„EPDM D-Profil 9×10 selbstklebend Shore 60"*

**Option C2 – EPDM closed-cell foam rubber strip**
- Rectangular strip 10 × 10 mm, cut to 12 mm per key
- 2 mm compression = 20 % → force ~0.15–0.4 N; very soft, no distinct onset click
- Better for slow, gradual aftertouch; less suited for precise entry-point detection
- Search term: *„EPDM Moosgummi geschlossenzellig Streifen 10 mm"*

**Option C3 – Combined D-profile + foam sandwich**
- D-profile (C1) bonded on top of foam strip (C2), cold-vulcanised together
- Phase 1 (0–2 mm): D-profile compresses → clear onset, defined resistance
- Phase 2 (2–4 mm): D-profile near collapsed, foam takes over → progressive softening
- Mechanically progressive without any calculation; tunable by varying foam thickness
- First experiment: measure C1 alone, then add foam layer and compare

**Decided layout for main keys:**
- Buffer, magnet, and Hall sensor clustered at front of key (~front 20 mm zone)
- Guide pin (hardened steel Ø2 mm) placed after damping zone, minimum 25 mm from Hall sensor centre
- Key underside is flat and clean — all functional elements are on the frame

#### Sensor Position (Main Keys)

- Hall sensor **at front floor** in dedicated pocket, before guide pin location
- Magnet on underside of key, directly above sensor
- Rest distance magnet–sensor: ~12–15 mm → voltage ~1.5–2.0 V
- End stop: ~4 mm distance → voltage ~3.5–4.0 V
- Aftertouch (felt/PORON stack compression): ~2 mm → voltage ~4.0–4.3 V
- PCB lies flat on base plate, sensor soldered lying (legs bent 90°), flat side up

#### VT Keys (Quarter-Tone Plane)

- Shorter lever, pivot further forward (spatially behind main keys)
- Sensing and guidance **mirrored from above**: PCB traverse fixed in frame above VT keys
- Hall sensor pointing down, magnet on top of VT key
- Elastomer stop (or O-ring) in upper traverse = aftertouch + end stop from above
- Firmware inversion: `value = MAX - raw`
- **Force path note:** With short VT lever, pivot rail takes increased reaction force (~1.5× finger force) → rail must be dimensioned accordingly (aluminium insert)

#### Print Materials

| Component | Material | Process |
|---|---|---|
| Key blanks (main + VT) | Polymaker PolyLite ASA | FDM, printed upright |
| Frame modules, bearing blocks | Tough Resin | SLA |
| Aftertouch buffer (Option A) | Silicone O-ring Shore A 30–40 | Purchased part |
| Aftertouch buffer (Option B) | Elastic 50A slotted hollow cylinder | SLA (Formlabs) |
| Aftertouch buffer (Option C1) | EPDM D-profile 9×10 mm Shore A 60 | Purchased, cut to length |
| Aftertouch buffer (Option C2) | EPDM closed-cell foam strip 10×10 mm | Purchased, cut to length |
| Aftertouch buffer (Option C3) | C1 + C2 sandwich, cold-vulcanised | Purchased + bonded |
| Guide pin (all options) | Hardened steel Ø2 mm (nail drill bits), 25 mm from sensor | Ordered |
| Structural insert supports | Aluminium square tube 10×10×1 mm | Purchased, bonded in |

#### Base Frame Concept: Aluminium Tube Frame with Printed Node Connectors

Instead of a plywood base plate: **aluminium square tube frame** with printed ASA node connectors.

**Connection principle:**
- Aluminium tubes butt-join into printed ASA connectors
- Connectors have internal **knurling** (0.3–0.5 mm deep, 0.8–1.0 mm pitch) → mechanical form-lock for epoxy → adhesion independent of plastic–metal adhesion
- Bond with epoxy (UHU Endfest / Loctite EA 9461), aluminium roughened and degreased beforehand
- **M4 heat-set inserts** (Ruthex or similar) in ASA connectors (200–220°C soldering iron, Ø5.7 mm bore)
- Screws from outside through aluminium tube into heat-set inserts → mechanical retention in addition to bonded joint

**Advantages over plywood:**
- Lighter and stiffer
- Fully demountable despite bonded tubes
- Octave modules individually mountable and replaceable
- Node connectors simultaneously serve as mounting points for pivot rail, sensor bridge, and supports

### 5.2 Housing

- Wooden corpus (plywood/MDF as base structure, solid wood veneer for appearance)
- Aluminium rails for guidance and rigidity
- Target stage-box dimensions: depth ≤ 350 mm, height ≤ 120 mm

### 5.3 Scope

Decided:
- Base keyboard: 5 octaves + 1 C = 61 keys (classic organ/synth format)
- Quarter-tone extension: doubled key layout (additional quarter-tone row)
- Advantage: standard spare parts from 61-key instruments are readily available for sensing and mechanics

To clarify:
- Whether the topmost additional C+¼ is implemented as its own key (122 vs. 121 keys total)

---

## 5b. Firmware Architecture

### Design Principle: Two-Controller Separation

Processing is split between two independent units – clear responsibilities, independently upgradeable.

#### Teensy 4.1 – Sensor Front-End (Real-Time)

- Single responsibility: raw data acquisition with maximum achievable precision
- Hard real-time loop without OS jitter (no Linux, no RTOS needed)
- 122 channels via 8× CD74HC4067 mux, ADC scan at fixed rate
- Velocity: time between two voltage thresholds (requires µs resolution → only feasible on Teensy)
- Aftertouch: last portion of travel from the same analog signal
- Data transmission **compressed** – events only on state change
- Teensy should remain autonomous in the scan loop and should not depend on host polling

**Compressed event format (draft):**

| Field | Width | Content |
|---|---|---|
| Key index | 7 bit | 0–121 |
| Type | 2 bit | down / up / aftertouch |
| Value | 12 bit | velocity or aftertouch intensity |
| Timestamp | 16 bit | µs relative to last event |

→ ~4 bytes/event, only on change. Channels with no movement are not transmitted.

Interface to the system controller: push-style event stream (UART preferred as baseline). A separate control/calibration path may be split off if this later proves cleaner than a single duplex channel.

#### ESP32 – System / Control Layer (Current Preferred Intermediate Stage)

- Reads expressions, pedals, wheels, buttons, and other slow controls
- Orchestrates calibration sequences for the Teensy front-end
- Stores settings and operating modes
- Can already emit standalone MIDI / MPE without requiring the Raspberry Pi layer
- Provides a clean middle stage between raw sensor front-end and optional high-level host processing

#### Raspberry Pi – Protocol Back-End

- Receives compressed events from Teensy
- Transforms to MIDI, OSC, and further formats
- No real-time constraint at this level (latency budget sits in the Teensy)
- Optional rather than mandatory in the current architecture; the ESP32 layer may already cover standalone MIDI / MPE operation
- **Phase 2:** SuperCollider directly on RPi (Sclang + scsynth)
  - Native OSC support in SC
  - Tuning tables, synthesis, routing all in Sclang
  - RPi 4/5 sufficient for SC synthesizer layer
  - Instrument becomes DAW-independent

### Upgrade Stages

| Phase | Configuration |
|---|---|
| 1 (current real-time core) | Teensy front-end only |
| 2 | Teensy → ESP32 (standalone MIDI / MPE, calibration + controls) |
| 3 | Teensy → ESP32 → RPi (protocol flexibility / OSC / SuperCollider) |
| 3b | MPE layer: per-note pitch bend from aftertouch zone → Bebung effect |

**Key architectural rule:** the Teensy layer remains the real-time master for sensing, while ESP32 / RPi layers are additive system and protocol layers.

### Sensor Environment / Drift Notes

- Hall-sensor drift risk is considered manageable if ferromagnetic parts are kept away from the immediate sensor zone.
- Steel guide pins should preferably stay about `30 mm` from Hall sensor centres where packaging allows; `25 mm` remains the hard lower design limit already used elsewhere.
- Brass mounting parts are acceptable close to the Hall sensors; for the adjustable KLAK20 sensor rail, brass/aluminium fastening hardware is currently preferred over steel.
- Practical mounting consequence: for the KLAK20 sensor rail, printed slot nuts / nut stones with embedded brass nuts are currently preferred over steel T-nuts.
- Keep Hall sensors and magnet paths at least about `30 mm` from the outer housing skin in zones where metal stands or brackets can approach; `40 mm` is preferred in exposed areas.
- Avoid locating transformers, strong power supplies, loudspeaker magnets, or other magnetic sources directly under or on the instrument.
- The VT design may deliberately use a steel upper reaction rail if that rail is kept structurally separate from the Hall sensor rail and sufficiently far from the sensor path.

### Phase 3b: Bebung via MPE (Optional Expressive Layer)

The Hall sensor already measures the full travel continuously, including the elastomer aftertouch zone. This makes a Bebung effect physically feasible without any hardware changes:

- **Bebung principle:** Post-strike pressure modulates pitch – the only historical keyboard instrument with this capability was the clavichord (tangent stays in contact with string).
- **MPE implementation:** Each key on its own MIDI channel (1–15). Aftertouch zone maps to both Aftertouch intensity (CC) *and* a small per-note Pitch Bend (±N cents, configurable). Other simultaneously held notes are unaffected.
- **Firmware split:** lower aftertouch range → intensity; upper range → pitch modulation. Boundary configurable.
- **Hardware requirement:** none – sensor, mechanics, and event format already support it.
- **Constraint:** MPE limits simultaneous expressive notes to 15. Sufficient for impressionistic playing style; not a limitation for this instrument's primary use case.

This option is kept open deliberately (maximize options, test later). The 24-tone mapping remains the base; MPE is an additive expressive layer for Phase 3.

---

## 6. Reference Projects & Literature

- **Fokker Organ** (31-tone equal temperament): Historical reference instrument
- **Tonal Plexus (H-Pi Instruments)**: Commercial microtonal MIDI keyboard
- **Lumatone**: Isomorphic honeycomb layout, 280 keys, MPE
- **Jankó keyboard**: Symmetric layout, all keys identical across all keys
- **Teensy USB-MIDI** (PJRC official docs): https://www.pjrc.com/teensy/td_midi.html
- **MIDI Polyphonic Expression (MPE)**: https://midi.org/mpe
- **Xenharmonic Wiki**: https://en.xen.wiki

---

## 7. Open Questions / Next Steps

- [x] Layout decision: Kassel Principle (Organ St. Martin) – two height-offset rows behind the standard keys
- [x] Sensor concept: Hall effect sensor per key, magnet on key, elastomer stop for aftertouch – no FSR, no keybed purchase
- [x] Scope: 61 base keys (5 octaves + 1 C)
- [x] MIDI protocol: 24-tone mapping, no MPE; Scala tuning in Logic Pro / SuperCollider
- [x] Mechanics: custom build fully defined (lever, pivot, guide, weight, spring, end stop, O-ring aftertouch)
- [x] Sensor position main keys: Hall sensor at front floor pocket in front zone, magnet under key, guide pin placed after damping zone
- [x] Aftertouch solution: felt (1.2 mm) + PORON (4 mm) stack with Kapton sensor isolation; target additional ~2 mm controlled travel
- [x] Frame concept: half-octave SLA modules, aluminium square tube as structural insert
- [x] Filament: Polymaker PolyLite ASA (Tg 108°C, 3 kg ordered)
- [x] Electronics: A1324LUA-T ordered (50 pcs), CD74HC4067 mux, Teensy 4.1, VS Code + PlatformIO
- [ ] Build test bench: one main key with Hall sensor, felt/PORON stack, steel guide pin (>=25 mm from sensor), spring, weight
- [ ] Playability test: mock-up for reach check (accessibility of half-steps+¼)
- [ ] Determine exact quarter-tone key dimensions (width, length, travel, height offset)
- [ ] Pivot position analysis: optimal pivot location for main and VT keys
- [ ] After test bench: 1-octave build for playability test by the pianist

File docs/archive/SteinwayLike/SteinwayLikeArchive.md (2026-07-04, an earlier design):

# Steinway-Like Archive

This document freezes the previously explored piano-like intermediate state as an archive snapshot.

Archived naming note:

- `VT` is the historical archive label for the quarter-tone key family and corresponds to the active `QT` terminology
- this archive snapshot predates the active four-family naming `MWT`, `MST`, `QWT`, `QST`

Project shorthand: `Steinway-like` does **not** mean reverse-engineered Steinway geometry. It means a deeper, more piano-oriented action family with comparatively long front lever arms, piano-like pivot placement, and a correspondingly heavier mechanical category than the newly selected synth / semi-weighted target.

## Status

- Archived: June 2026
- Reason for archive: the pianist now clearly prefers a synthesizer / semi-weighted keyboard with aftertouch, and the Access Virus C feel is currently the strongest reference
- Active successor direction: Access Virus C / Fatar-style synth action with dedicated aftertouch integration

## What Is Archived Here

The archived branch includes the current geometry and packaging assumptions for:

- piano-like main-key pivot placement
- front-side standard-key aftertouch package
- VT geometry behind the pivot
- reinforced pivot-frame concept for the deeper action family
- MP5-derived reference proportions used as a design anchor

## Archived Main-Key Reference Geometry

Archived normal-key baseline from the current documentation:

- White-key front reference point at rest: `O = (0, 0)`
- Main-key pivot axis: `Y = 210.0 mm`, `Z = -24.0 mm`
- Front guide pin: `Y = 60.0 mm`
- White-key bottom-stop front travel: `10.8 mm`
- Black-key bottom-stop front travel: `10.0 mm`
- White-key bottom-stop rotation: `2.95 deg`
- Black-key bottom-stop rotation: `3.66 deg`

Archived current standard-key aftertouch construction state:

- Front first contact / end-stop contact zone: `Z = -43.0 mm`
- Aftertouch hard end: `Z = -46.0 mm`
- Additional aftertouch rotation: about `1.10 deg`
- White-key front point with aftertouch: `14.83 mm`, `4.05 deg`
- Black-key front reference with aftertouch: `13.0 mm`, `4.76 deg`

## Archived VT Geometry Snapshot

Archived VT reference state from the current documentation:

- VT pivot axis: `Y = 245.0 mm`, `Z = 10.0 mm`
- VT rear guide pin: `Y = 290.0 mm`
- VT return spring anchor: `Y = 263.0 mm`
- Current translated VT aftertouch zone: `Y = 370.0 mm`
- VT rear hard end-stop: `Y = 380.0 mm`
- VT Hall sensor zone: `Y = 390.0 mm`
- Pin-to-sensor clearance in the translated package: `100 mm`

Archived VT lever interpretation:

- VT row above whole tones: front lever arm `155 mm`
- VT row above semitones: front lever arm `125 mm`
- A `3.0 mm` local compression at `Y = 370 mm` corresponds to about `3.72 mm` front travel on the whole-tone VT row and `3.00 mm` on the semitone VT row

## Archived Structural Interpretation

The archived deeper-action branch also includes the following structural assumptions:

- main-key pivot category remains piano-like rather than synth-like
- VT pivot packaging is the main geometric bottleneck
- VT lever body may remain around `13 x 20 mm` in the main load-bearing zone
- VT pivot region may locally grow to about `22 mm` total height
- pivot bushings / local bearing inserts may use Tough Resin with about `5 mm` wall thickness

## Archived MP5 Reference

The archived branch also includes the MP5 comparison gathered in the separate reference note:

- action family confirmed publicly: `AHA IV-E with AR technology`
- public external envelope confirmed: `1356 x 340 x 172 mm`
- project-side MP5-like working pivot reference: `Y = 210 mm`, `Z = -24 mm`

That MP5 note remains useful as a proportional reference for the archived branch, but it is not a factory-proven internal Kawai CAD dataset.

## Active Direction After the Archive Decision

This archive means the project should no longer treat the above geometry as the active target mechanism.

New active mechanical direction:

- category: synthesizer / semi-weighted
- primary feel reference: Access Virus C
- keybed family reference: Fatar keyboard feel
- aftertouch integration should be designed as a first-class feature, not as an add-on to a hammer-action-like mechanism
- new layout work should start from the lighter synth-action category rather than from the archived piano-like proportions

## Source Documents Preserved by This Archive

The archive snapshot is distilled from the following current project files:

- `docs/BuildGuide.md`
- `docs/Research.md`
- `docs/archive/SteinwayLike/MP5GeometryReference.md`

These files may continue to evolve, but this archive records the state that should now be regarded as the closed `Steinway-like` branch.

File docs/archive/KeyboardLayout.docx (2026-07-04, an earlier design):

# Layout: Standard

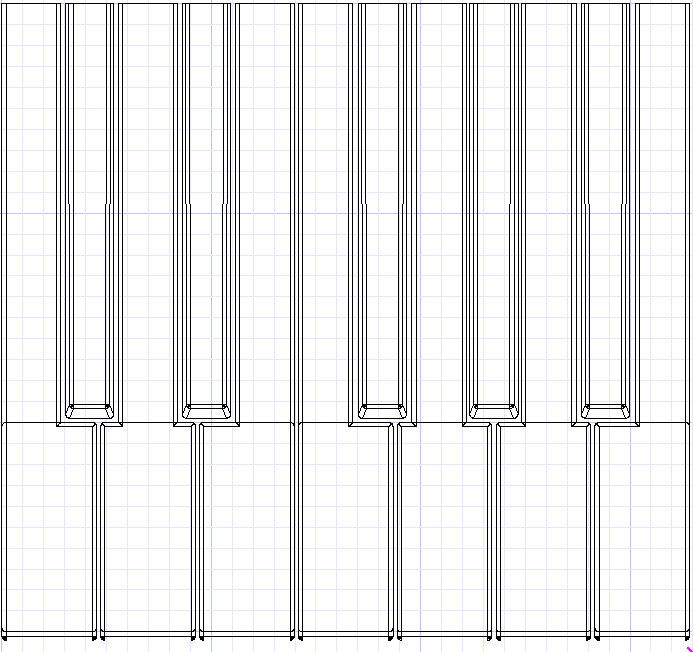
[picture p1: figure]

# Layout: bisheriger Favorit

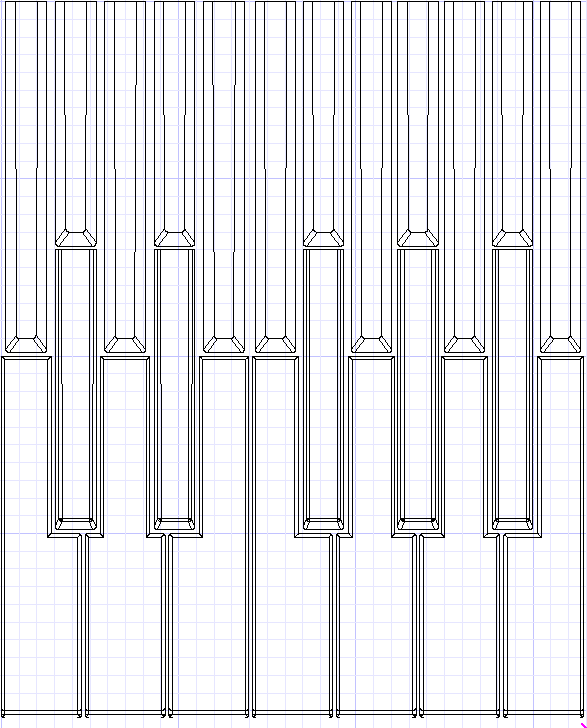
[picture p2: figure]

# Layout: Verkürzte Version

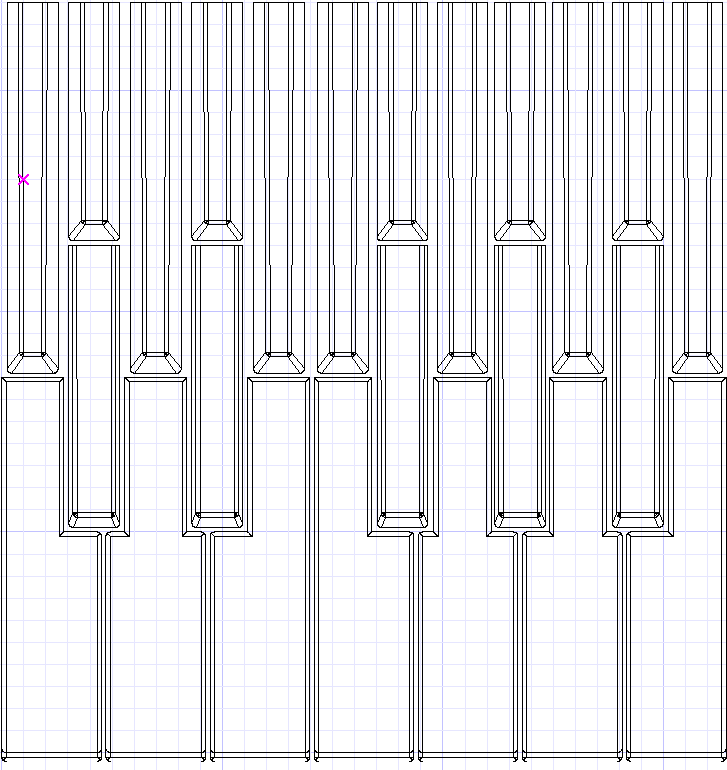
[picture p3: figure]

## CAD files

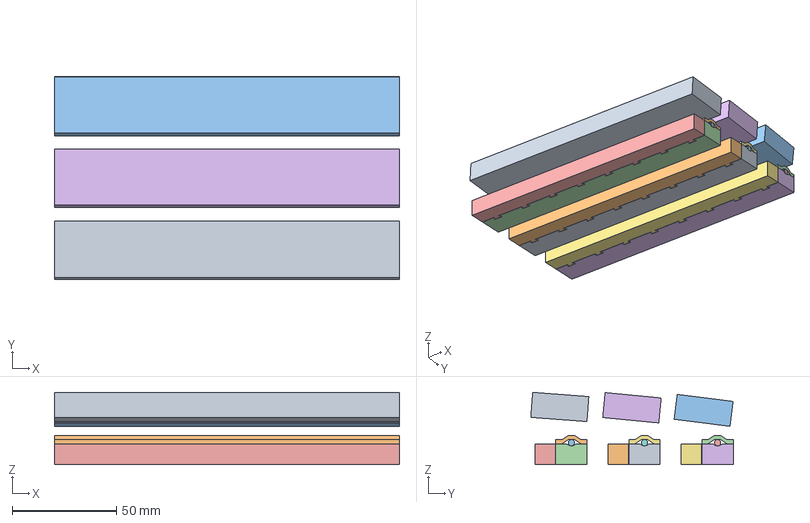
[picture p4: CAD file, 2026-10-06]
docs/CAD/_Assemblies/MainModel.FCStd
165.2 x 97.0 x 34.6 mm
bindStamp
bFelt
bRubberChord
bBufferBlock
bSensorBlock
bindStamp031
bFelt031
bRubberChord031
bBufferBlock031
bSensorBlock031
bindStamp032
bFelt032
bRubberChord032
bBufferBlock032
bSensorBlock032

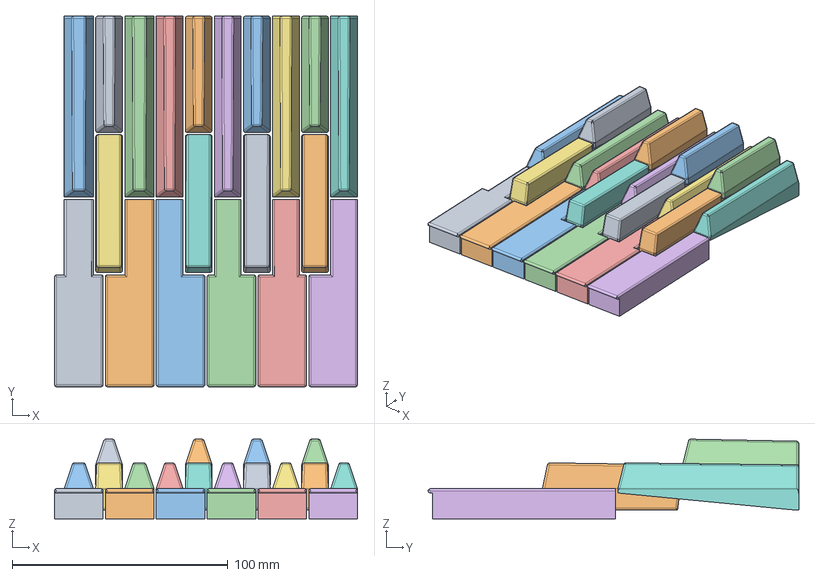
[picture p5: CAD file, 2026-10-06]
docs/CAD/_Assemblies/KeysPreview.FCStd
140.6 x 172.0 x 37.0 mm
bMWTKey151 x 2
bMWTKey152 x 2
bMWTKey153 x 2
bMWTKey154 x 2
bMWTKey155 x 2
bMWTKey156 x 2
bMSTKey098 x 2
bMSTKey099 x 2
bMSTKey100 x 2
bMSTKey101 x 2
bQWTKey154 x 2
bQWTKey155 x 2
bQWTKey156 x 2
bQWTKey157 x 2
bQWTKey158 x 2
bQWTKey159 x 2
bQSTKey060 x 2
bQSTKey061 x 2
bQSTKey062 x 2
bQSTKey063 x 2

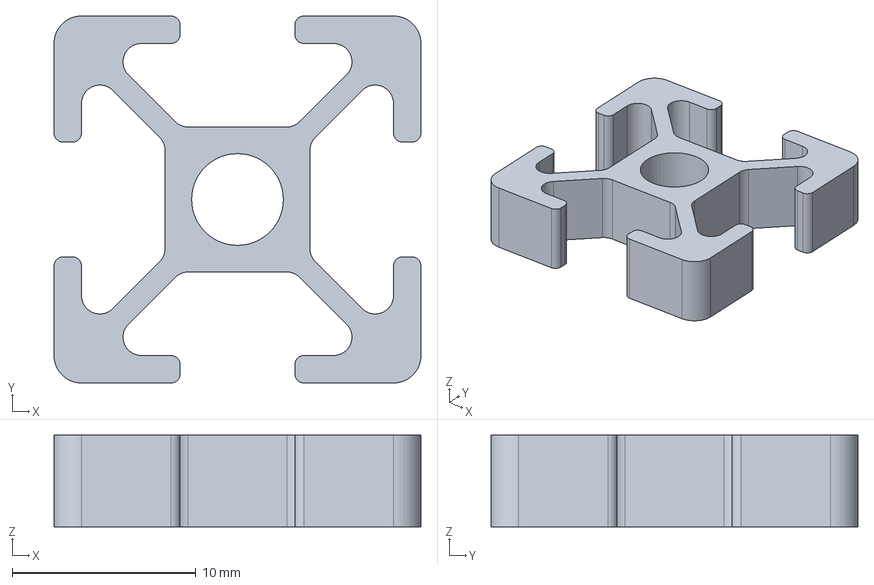
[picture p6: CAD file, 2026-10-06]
docs/CAD/_BoughtParts/Klak20.FCStd
20.0 x 20.0 x 5.00 mm

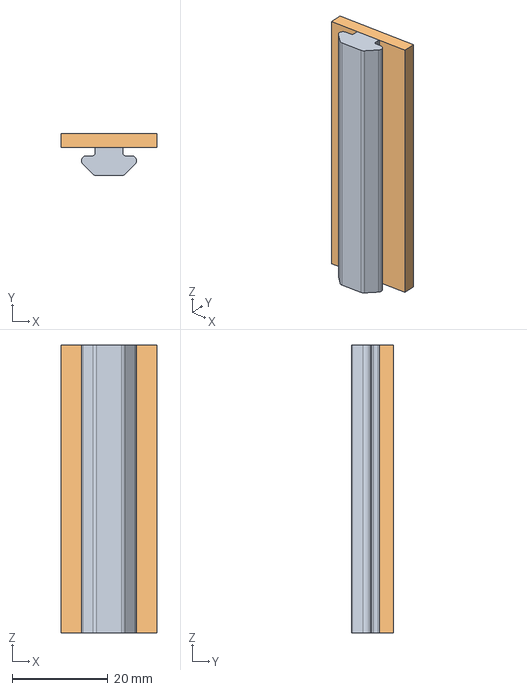
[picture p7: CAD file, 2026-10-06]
docs/CAD/_BuildPrototypes/Klak20_Slider_Bonded.FCStd
20.0 x 8.85 x 60.0 mm
bKlak20SliderBonded
bKlak20MountBonded

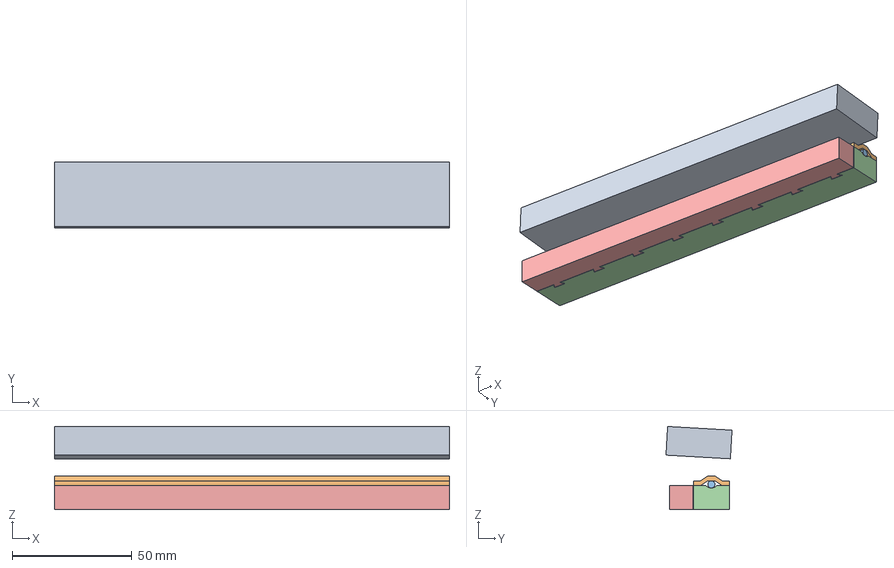
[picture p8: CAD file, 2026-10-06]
docs/CAD/_Design/ReactionGroups.FCStd
165.2 x 27.6 x 34.7 mm
bindStamp
bFelt
bRubberChord
bBufferBlock
bSensorBlock

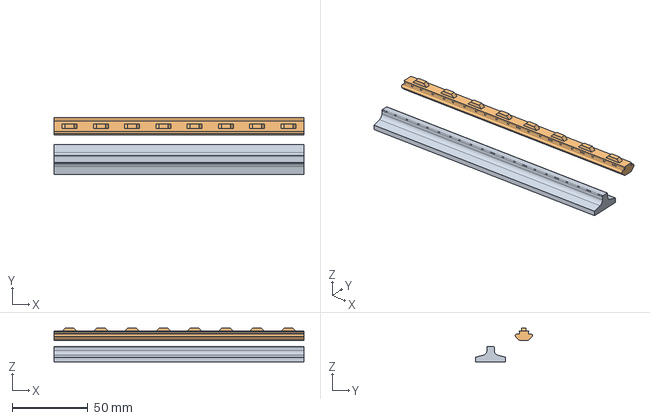
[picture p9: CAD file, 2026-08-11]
docs/CAD/_STPs/ZeroStopParts.step
165.2 x 37.8 x 22.2 mm
pZeroStop
bKlak20SliderBonded001

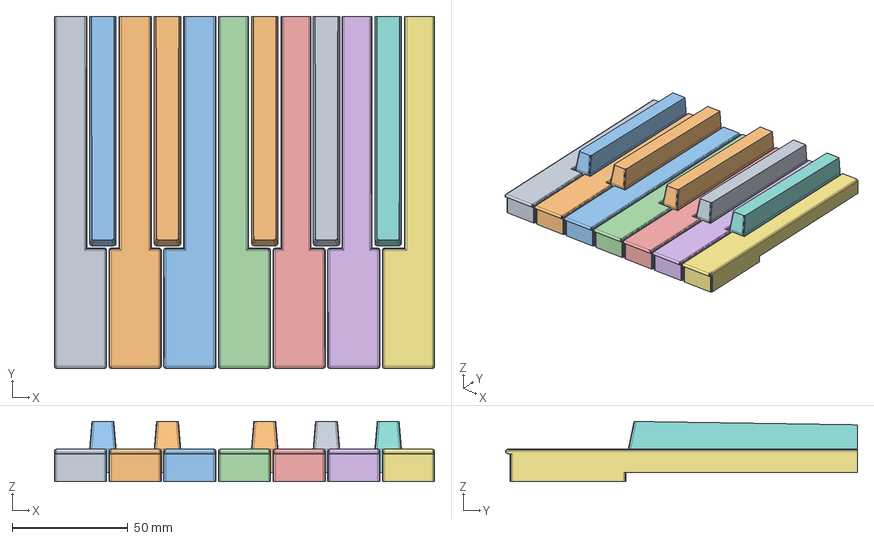
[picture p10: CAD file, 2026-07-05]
docs/CAD/QTKB-blocks/Standard.stp
164.2 x 152.0 x 26.0 mm

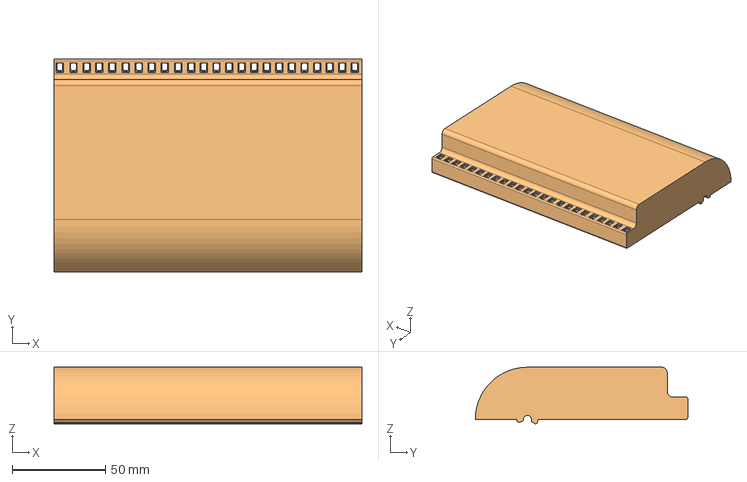
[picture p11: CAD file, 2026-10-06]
docs/CAD/_Design/LeverRear.FCStd
165.2 x 114.0 x 30.4 mm
pPTFETubes
pLeverRearYZWithGuidance

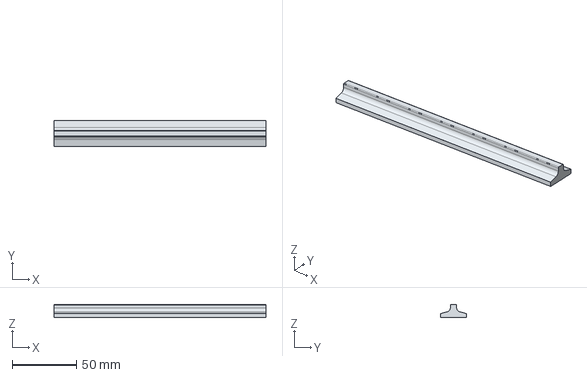
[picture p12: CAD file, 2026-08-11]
docs/CAD/_STPs/ZeroStop-pZeroStopFusion.step
165.2 x 20.0 x 10.0 mm

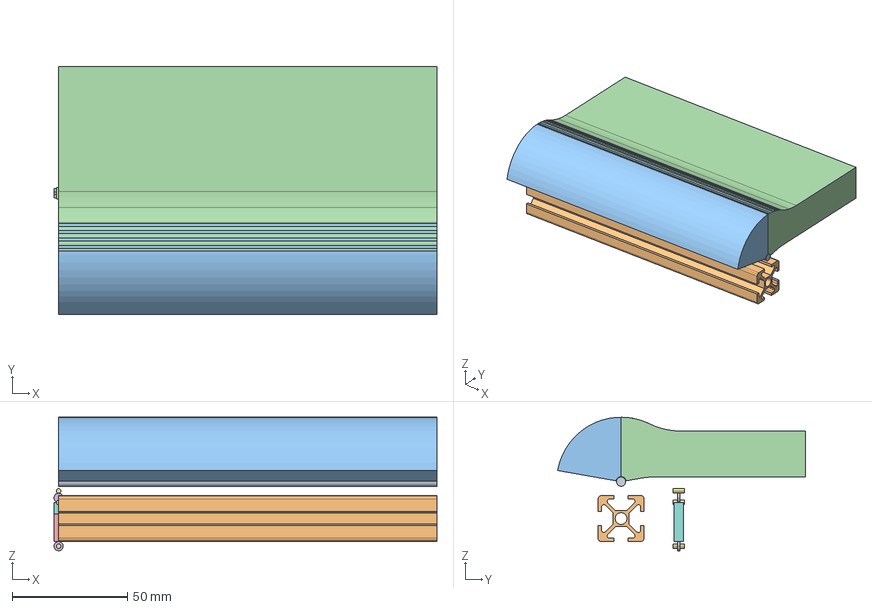
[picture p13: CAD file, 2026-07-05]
docs/CAD/QTKB-blocks/Springs.stp
166.2 x 107.6 x 58.0 mm

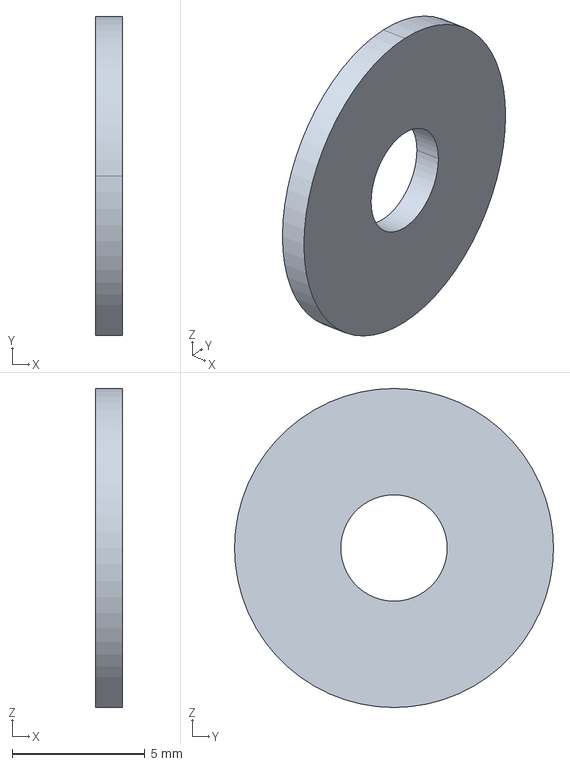
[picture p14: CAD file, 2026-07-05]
docs/CAD/QTKB.stp
1.00 x 12.0 x 12.0 mm

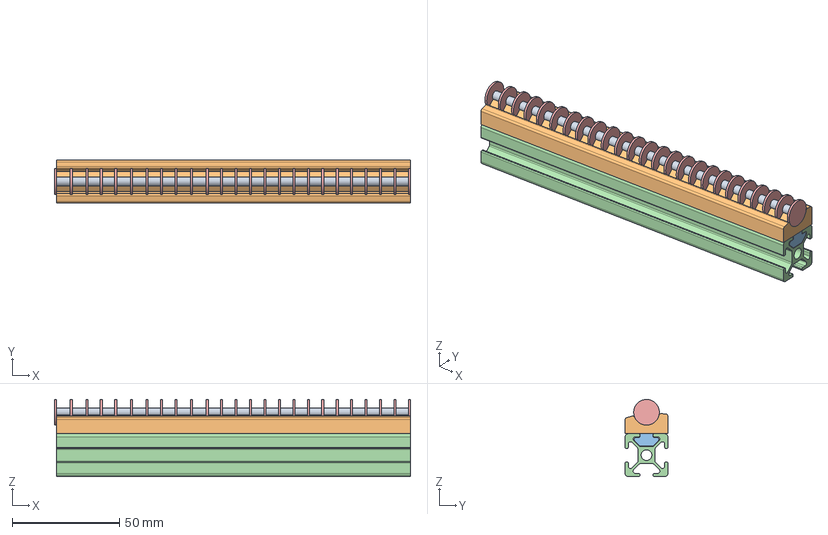
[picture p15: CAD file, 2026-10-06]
docs/CAD/_Design/PivotAxis.FCStd
166.2 x 20.0 x 36.0 mm
bBrassShaft
pPivotAxisMount
bKlak20SliderBonded005
bKlak20Rail008
pWashers

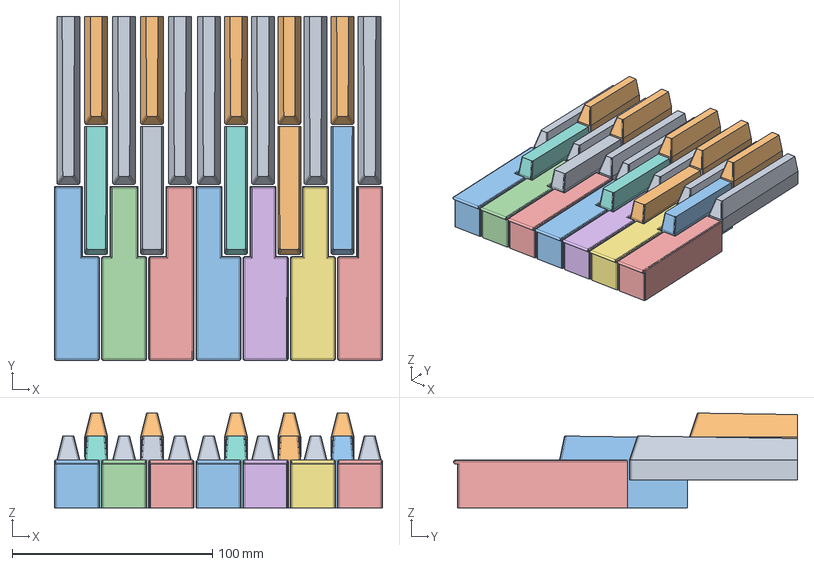
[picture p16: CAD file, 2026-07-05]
docs/CAD/QTKB-blocks/KeysShort.stp
164.2 x 172.0 x 47.4 mm

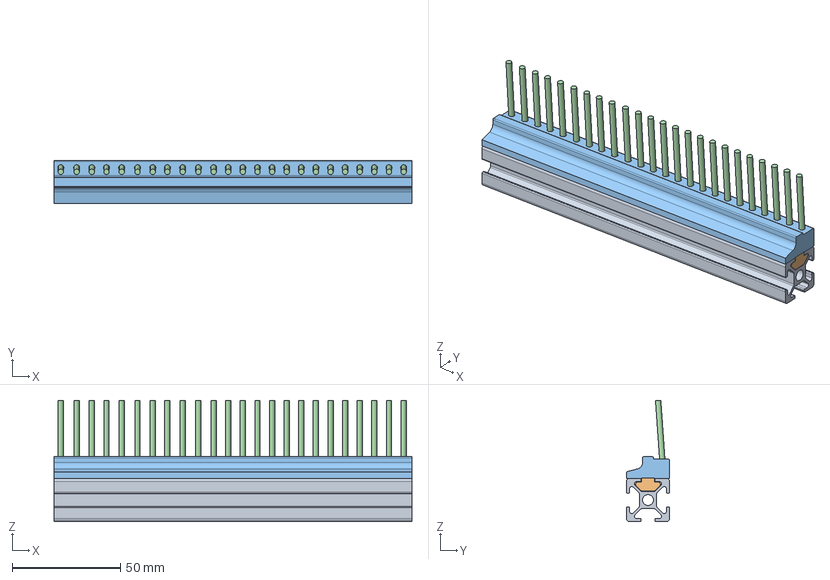
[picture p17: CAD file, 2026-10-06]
docs/CAD/_Design/ZeroStop.FCStd
165.2 x 20.0 x 56.0 mm
bKlak20Rail004
bKlak20SliderBonded009
pZeroStop
pGuidanceSplints

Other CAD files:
docs/CAD/_BuildParts/ZeroStopParts.FCStd
docs/CAD/Master.FCStd
docs/CAD/_BoughtParts/Nuts.FCStd
docs/CAD/_BuildParts/PivotAxisParts.FCStd
docs/CAD/QTKB-blocks/A_SteelPins.stp
docs/CAD/QTKB-blocks/Buffer_V0.stp
docs/CAD/QTKB-blocks/KeyEndSTop.stp
docs/CAD/QTKB-blocks/KeysLong.stp
docs/CAD/QTKB-blocks/Klak20.stp
docs/CAD/QTKB-blocks/P_BrassV0.stp
docs/CAD/QTKB-blocks/P_SteelV0.stp
docs/CAD/QTKB-blocks/PivotCarrier_V0.stp
docs/CAD/QTKB-blocks/RctnGrp_BrassV0.stp
docs/CAD/QTKB-blocks/RctnGrp__SteelV0.stp
docs/CAD/QTKB-blocks/V2BL-Layout.stp
docs/CAD/QTKB-blocks/Washer.stp
docs/CAD/QTKB-blocks/X_S_00.stp
docs/CAD/QTKB-blocks/X_S_01.stp
docs/CAD/QTKB-blocks/X_S_02.stp
docs/CAD/QTKB-blocks/YZClrnc_BrssPns.stp
docs/CAD/QTKB-blocks/YZClrnc_StlPns.stp
docs/CAD/_BoughtParts/Washers.FCStd
docs/CAD/_BuildPrototypes/Klak20_Slider_Bolted.FCStd
docs/CAD/_Design/Keys.FCStd
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

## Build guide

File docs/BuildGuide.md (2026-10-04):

# Quarter-Tone Keyboard (QTKB) – Build Guide

This is the active build guide for the synth / semi-weighted workstream and the single active technical source for geometry, prototype rules, and build decisions.

Public shorthand for GitHub-facing material: `QTKB`.

The previously documented piano-like intermediate branch is no longer active and is preserved under `docs/archive/SteinwayLike/`.

## Active Branch Context

- Active branch: June 2026 onward
- Primary feel reference: Access Virus C
- Keybed family reference: Fatar-style synth action
- Active mechanical category: synthesizer / semi-weighted with integrated aftertouch

Active design anchors:

- shallower package than the archived piano-like branch
- consistent feel across all `122` keys
- quarter-tone keys may differ in force and geometry, but must remain inside the same overall action family
- aftertouch is part of the base key-travel design, not an add-on

## Active Reference Interpretation

Current externally supported reference facts:

- the keyboard Virus C variant (`Virus KC`) is a `61`-key instrument
- it is described publicly as `61 semi-weighted keys`
- it supports velocity and monophonic aftertouch at the keyboard level
- current Fatar synth families such as `TP/9S`, `TP/8S`, and `TP/8SK` are explicitly listed as synthesizer keyboards and are offered with `61`-key variants and aftertouch options

Current working conclusion:

- the player-facing `MT` dimensions can remain unchanged
- the player-facing `QT` top-side dimensions can also remain unchanged for now
- the redesign focus is the internal mechanics, packaging depth, return system, sensor placement, and aftertouch integration

Current interpretation of the reference aftertouch category:

- public Fatar information suggests pressure-oriented aftertouch sensing with very little intentional extra travel
- for this project, Hall-based aftertouch should therefore use a small but deliberate reserve travel instead of blindly copying a near-zero-travel pressure-strip concept
- the active design question is not a published Fatar aftertouch travel number, but the reserve travel that is musically useful in this custom Hall-based action

## Frozen Player-Side Dimensions

These player-facing dimensions remain active until contradicted by prototype evidence:

- CAD source of truth for detailed layout values: `docs/CAD/Design/MasterLayout.csv`
- `MT` octave width at the white-key front: `165.2 mm`
- `MWT` head width: `22.6 mm`
- `MWT` air gap to neighboring key: `1.0 mm` in `X` and `Y`
- `MWT` effective white-key pitch at front: `23.6 mm`
- `MWT` head length: `50.0 mm`
- `MWT` lip length: `2.0 mm`
- `MWT` lip height: `2.0 mm`
- `MWT` tail length: `35.0 mm`
- `MWT` body height: `14.0 mm`
- `MST` black key width: `12.5 mm`
- `MWT` and `QWT` rear-tail raster: equidistant within `C-E` at `13.6 mm` and independently equidistant within `F-B` at `12.475 mm`; the `E/F` transition is intentionally discontinuous
- Pivot layout: retain an equidistant pivot raster for the first printed layout check; correct any required local offset with separately printed levers or, preferably, replaceable SLA bearing inserts.
- `MST` start position: `Y = 51.0 mm`
- `MST` visible length: `64.0 mm`
- `MST` black key height above white: `12.0 mm`
- `MST` body height: `10.0 mm`
- `MST` top slope: `1.0 deg`
- `QT` width: `<= 12.5 mm`
- `QWT` top-side span: `Y = 86-170 mm`
- `QWT` rest height above `MWT` plane: `+12 mm`
- `QST` top-side span: `Y = 116-170 mm`
- `QST` rest height above `MWT` plane: `+24 mm`
- `QT` front-travel target band: about `8-10 mm`

## Build Phase Overview

| Phase | Content | Status |
|---|---|---|
| 1 | Define synth-action geometry baseline | Active |
| 2 | Build single-key synth-action test bench | Open |
| 3 | Verify Hall sensor and aftertouch package | Open |
| 4 | Derive quarter-tone integration for the synth branch | Open |
| 5 | Build one-octave mock-up | Open |
| 6 | Electronics prototype | Open |
| 7 | Firmware integration | Open |
| 8 | Full mechanical iteration | Open |

## Phase 1: Active Geometry Baseline

Coordinate system rule:

- global origin: `O = (0, 0, 0)` at the front-left top corner of the lowest `MWT` key at rest
- `X` points rightward toward higher notes
- `Y` points rearward from the player
- `Z` points upward; the resting `MWT` key-top surface is the reference plane `Z = 0`

Active geometry rules:

- use main-key pivot baseline `Y = 210 mm`, `Z = -12 mm`
- `QT` keys are short secondary levers on the shared main pivot axis, not on a separate `QT` pivot axis
- do not silently revive archived defaults such as `Y = 210 mm`, `Z = -24 mm` or the earlier two-axis proposal `MT = (195, -12)`, `QT = (235, 6)`
- treat splint, buffer, and sensor as one compact reaction group per key family while keeping the four family lanes `MWT`, `MST`, `QWT`, and `QST` separate from each other
- keep aftertouch inside the core travel design from the beginning

Active support and stop architecture:

- use the shared pivot axis plus a rear zero-stop guide splint as the two
	separated points of lateral `X` guidance; do not place the guide splint in
	the aftertouch-buffer reaction group
- use a simple laid-in pivot axle with spacer washers as the current key-spacing baseline
- the pivot axis is now a concrete, print-oriented CAD model at `docs/CAD/_Design/PivotAxis.FCStd`; its detailed geometry is exported in `docs/CAD/_Design/PivotAxis/PivotAxis.csv`
- treat the current pivot-holder wrap as provisional; first-print feedback suggests the present lever-direction capture is too small, so a roughly `180 deg` axle wrap should be tested as the next prototype candidate
- reduce the local lever-side support land in the pivot washer zone to `5 mm` where needed to clear the spacer-washer package inside the available `6.84 mm` width; treat this as an active prototype assumption, not yet as a fully validated final dimension
- allow the axle and spacer stack to be bonded into a removable holder cradle with `UHU Endfest`
- use replaceable Tough Resin bearing inserts rather than making the structural frame the wear part
- use Tough Resin for the local washer-contact region in the current prototype direction
- keep only the rear zero stop behind the pivot; the terminal end stop stays on the split-pin / guide line
- the rear zero stop is now a concrete, print-oriented CAD model at `docs/CAD/_Design/ZeroStop.FCStd`; its active global references are `ZStopCenterY = 285 mm` and `ZStopTopZ = -12 mm` in `docs/CAD/Master/Globals.csv`
- place the rear guide splint / PTFE package at the zero-stop structure, about
	`75 mm` behind the pivot, while keeping it mechanically separate from the
	hard zero-stop contact
- move the key-side zero-stop lip slightly forward of the rear guide line so
	its stop face remains unobstructed by the splint and guide package
- preserve the tail volume behind the pivot for zero-stop packaging, spring hardware, and optional trim mass

Active packaging rules:

- `6 mm` maximum lever body within a `6.8 mm` per-key lane
- `16-18 mm` first-pass box height over most of the hidden lever body
- `20-22 mm` local build-up around pivot, spring eye, guide-bushing pocket, and optional weight pocket
- prototype the lever, cradle, stop, and support geometry in `FDM` first before introducing metal construction

K20 support-frame height:

- `K20FrameZ = -32 mm` is the common nominal global `Z` height for the K20 profiles supporting both the pivot axis and rear zero stop.
- The local `PivotAxis.csv` value `K20Z = -20 mm` is the offset from the pivot's local origin at `PivotAxisZ = -12 mm`; it therefore resolves to the same global height, `Z = -32 mm`.
- Pivot and zero-stop supports remain separately vertically adjustable around this nominal value. Further K20 profiles may use `K20FrameZ` when the supports are connected into a common frame.

Current key-family naming:

- `MWT` = Main Whole-tone key
- `MST` = Main Semitone key
- `QWT` = Quarter Whole-tone key
- `QST` = Quarter Semitone key

### Open Data And Prototype Questions

Data still worth collecting:

- exact Access Virus C keyboard family or the closest reliable Fatar equivalent
- representative front travel of the reference action
- key length and effective pivot distance of the reference action
- aftertouch onset position and useful reserve travel
- force impression over the main stroke and aftertouch zone
- packaging depth required for the reference category

Immediate CAD / prototype questions:

- What is the minimum viable main-key depth for the active branch?
- Can the Hall sensor sit in front of, above, or behind the pivot without creating feel penalties?
- How should `QT` keys be packaged so they remain consistent with the shallower main-key action?
- Which return-force concept best matches a Fatar-like synth feel in a custom build?
- How much pivot-axle wrap is actually needed for sufficient lever-direction stiffness, and is a roughly `180 deg` capture practical with the current washer-retained axle stack?
- Is the local `5 mm` support land at the pivot washer zone sufficient once the local load-bearing region is switched to Tough Resin?

### Immediate Deliverables

- identify usable Access Virus C / Fatar reference measurements
- define first active main-key travel target
- define first active aftertouch travel target
- choose provisional pivot and sensor packaging concept for the shallow action
- derive first QT layout sketch relative to the new main-key geometry
- define first lane map for `MWT`, `MST`, `QWT`, and `QST` for split pins, buffers, and sensors
- define the first lever cross-section around a `6 mm` maximum body width and `16-18 mm` box height
- prototype the rear zero-stop, spring line, and optional trim-mass zone in FDM before any metal work

## Phase 2: Single-Key Test Bench

Immediate prototype goal:

- one main key in the new synth-action category
- one matching quarter-tone key concept for packaging comparison
- Hall sensor position and magnet geometry representative of the active branch
- integrated aftertouch travel reserve as part of the base design

The first prototype must answer:

- whether the intended synth-like feel is reachable with the chosen lever and return concept
- how much travel reserve is available for aftertouch without destroying the main playing feel
- how much depth the active branch actually needs

Current first-pass key-family tables:

### MWT Key

| Field | Current value | Note |
|---|---|---|
| Motion concept | Main lever | Standard white-key family |
| Front reference point | `Y = 0 mm`, `Z = 0 mm` | White-key front top edge at rest |
| Pivot axis | `Y = 210 mm`, `Z = -12 mm` | Active working baseline |
| Lever width | `6 mm` maximum | Shared current lever width inside a `6.8 mm` per-key lane |
| Box height over hidden lever | `16-18 mm` | FDM baseline |
| Box height at pivot section | `20-22 mm` | Local reinforced height |
| Normal front travel | `9.8 mm` | Current white-key reference under the fixed full-aftertouch geometry |
| Key angle at normal travel | `2.67 deg` | From `asin(9.8 / 210)` |
| Key angle at full aftertouch | `3.2 deg` | Fixed user value for the full-aftertouch end position |
| Spring start | `20 x 4 x 0.5 mm`, `22.0 mm` eye-to-eye at rest | First fixed start value without trim weights |
| Zero stop | `Y = 285 mm` | Hard printed rail |
| End stop | Split-pin / guide line | Terminal stop line |

### MST Key

| Field | Current value | Note |
|---|---|---|
| Motion concept | Main lever | Standard black-key family |
| Front reference point | `Y = 53.5 mm`, `Z = 12.0 mm` | Black-key top reference plane at rest |
| Pivot axis | `Y = 210 mm`, `Z = -12 mm` | Shared main-key pivot |
| Lever width | `6 mm` maximum | Shared current lever width inside a `6.8 mm` per-key lane |
| Box height over hidden lever | `16-18 mm` | FDM baseline |
| Box height at pivot section | `20-22 mm` | Local reinforced height |
| Normal front travel | `10.0 mm` | Current standard black-key travel |
| Key angle at normal travel | `3.66 deg` | From `asin(10.0 / 156.5)` |
| Key angle at full aftertouch | `4.3 deg` | Fixed user value for the full-aftertouch end position |
| Spring start | `20 x 4 x 0.4 mm`, `21.5 mm` eye-to-eye at rest | First fixed start value without trim weights |
| Zero stop | `Y = 285 mm` | Hard printed rail |
| End stop | Split-pin / guide line | Terminal stop line |

### QWT Key

| Field | Current value | Note |
|---|---|---|
| Motion concept | Short secondary lever | Shared main pivot axis, no separate QT pivot axis |
| Front reference point | `Y = 86 mm`, `Z = 12 mm` | QWT top front edge at rest |
| Pivot axis | `Y = 210 mm`, `Z = -12 mm` | Shared main-key pivot |
| Lever arm to front reference | `124 mm` | `210 - 86` |
| Top-side width | `<= 12.5 mm` | Current QT width limit |
| Visible length | `84 mm` | Top-side span `Y = 86-170 mm` |
| Rest height above MWT plane | `+12 mm` | Whole-step quarter-tone row |
| Normal front travel target | About `8-10 mm` | Current target band |
| Key angle at normal travel | `3.70-4.63 deg` | From `asin(8/124)` to `asin(10/124)` |
| Key angle at full aftertouch | `5.6 deg` | Fixed user value for the full-aftertouch end position |
| Box height at pivot section | `20-22 mm` | Shared first-pass reinforcement zone; use the upper end where the guide-bushing pocket sits in the `6 mm` body |
| Local QT body height | `16-18 mm` | Same first-pass box height as the main-key family; increase only where splint, spring, or local insert packaging demands it |
| Spring start | `25 x 4 x 0.4 mm`, `26.0 mm` eye-to-eye at rest | First fixed start value without trim weights |

### QST Key

| Field | Current value | Note |
|---|---|---|
| Motion concept | Short secondary lever | Shared main pivot axis, no separate QT pivot axis |
| Front reference point | `Y = 116 mm`, `Z = 24 mm` | QST top front edge at rest |
| Pivot axis | `Y = 210 mm`, `Z = -12 mm` | Shared main-key pivot |
| Lever arm to front reference | `94 mm` | `210 - 116` |
| Top-side width | `<= 12.5 mm` | Current QT width limit |
| Visible length | `54 mm` | Top-side span `Y = 116-170 mm` |
| Rest height above MWT plane | `+24 mm` | Semitone quarter-tone row |
| Normal front travel target | About `8-10 mm` | Current target band |
| Key angle at normal travel | `4.88-6.11 deg` | From `asin(8/94)` to `asin(10/94)` |
| Key angle at full aftertouch | `7.2 deg` | Fixed user value for the full-aftertouch end position |
| Box height at pivot section | `20-22 mm` | Shared first-pass reinforcement zone; use the upper end where the guide-bushing pocket sits in the `6 mm` body |
| Local QT body height | `16-18 mm` | Same first-pass box height as the main-key family; increase only where splint, spring, or local insert packaging demands it |
| Spring start | `25 x 4 x 0.4 mm`, `26.5 mm` eye-to-eye at rest | First fixed start value without trim weights |

### Shared Summary

| Field | Current value | Note |
|---|---|---|
| Return-spring line | `Y = 235 mm` | Common first spring line for all four key types |
| Pivot support land in washer zone | `5 mm` provisional | Local reduction to clear the spacer-washer package inside the available `6.84 mm` width; validate stiffness in prototype first |
| Zero-stop material | Printed hard rail, preferred `ASA`, `PETG` acceptable for fast tests | Height should be defined by the hard rail even when a damping layer is added |
| Zero-stop contact width in `Y` | `2.5-3.0 mm` | Narrow, defined contact band for repeatable rest height |
| Zero-stop contact width across lever | `4-5 mm` on a `6 mm` lever | Keeps contact defined without using the full width as a hard impact plane |
| Zero-stop damping option | Thin constrained solid `TPU` or `PORON` strip/profile in front of the hard rail | Preferred first damping approach; do not use a hollow profile as the default reference-defining stop |
| Zero-stop height adjustment | Shim or tape on hard rail | Prototype-friendly replacement for paper punching / key punching |
| Optional trim-mass zone | `Y = 255-285 mm` | Can stay in the original active zone; shrink-wrapped weight may also damp the zero stop when weights are used, but should not define the stop geometry |
| First trim-mass test piece | `5 g`, `19 x 11 x 3 mm` | Current available test weight; usable on a `6 mm` lever if mounted lengthwise in `Y` and upright in `Z` |
| First trim-mass test placement | Center about `Y = 275 mm` | Fits the restored active trim-mass zone well; use a local carrier or reinforced lever section if needed |
| Weight packaging note | `19 mm` in `Y`, `3 mm` across lever width, `11 mm` in `Z` | Standing lengthwise packaging is acceptable because height is available behind the pivot |
| Functional package lanes | `MWT`, `MST`, `QWT`, `QST` | Separate reaction-group lanes by key family; buffer and sensor remain packaged together, while the lateral guide is now at the rear zero stop |
| Reaction-group reference | `5 mm` behind the key front edge in the full-aftertouch tilt state | Current placement reference for each splint / buffer / sensor group |
| Rear-guide kinematic rule | Straight splint and oval PTFE tube at the rear zero stop | The pivot axis is the front `X` guide; the rear guide is the second `X` guide. Do not use a radial splint path or a guide at the aftertouch buffer. |
| Guide splint material and diameter | Brass, `2.5 mm` | Straight splint, tilted `4 deg` in its local `YZ` plane; round and polish its free end. The tilt centres the QST motion about the vertical tube near mid-stroke. |
| PTFE guide tube | `5 mm` OD, `4 mm` ID, compressed to about `4 mm` in `X` by `6 mm` in `Y` outside section | Mount vertically in global `Z`. The narrow `X` section provides lateral guidance; the taller `Y` section provides the required small `Y` compliance. Validate friction, wear, and lateral play on the prototype. |
| Guide tube length | `10 mm` axial bearing length | First prototype value for the rear guide only. It works with the pivot as the separated second bearing point and is not intended to constrain rotation about `Y`. |
| Splint free working length | `25 mm` | QST is the governing case: at a guide location about `75 mm` behind the pivot, full aftertouch causes about `9.4 mm` `Z` travel and `0.59 mm` `Y` migration. This length retains `10 mm` PTFE engagement with practical end reserve. |
| Guide engagement | Continuous through normal travel and full aftertouch | The splint must not leave the PTFE tube in the mechanical operating range. Do not reduce the `25 mm` free length toward `22 mm` before measured stroke, tube deformation, and assembly tolerances are known. |
| Guide block format | Straight rear-guide pocket at the zero-stop structure | Keep local side-wall and reinforcement checks, especially for `QWT` and `QST`; retain the hard zero-stop contact as a separate feature. |
| PTFE retention concept | Form-locking pocket plus adhesive | Roughen the outer PTFE surface first and use cyanoacrylate only as position-locking support, not as the primary structural element. |
| Guide governing case | `QST` | Validate residual rotation about `Y`, friction, `X` play, and the available `Y` motion with the physical prototype. |
| Optional aftertouch stamp catch guide | Fixed shallow tray around the key-side aftertouch stamp | Optional passive secondary guide only. Keep the stamp clear during normal travel and normal aftertouch; the tray catches exceptional side load from glissando or wide playing spans before the stamp can be pushed substantially sideways. |
| Catch-guide clearance | More than `0.5 mm` radial clearance around the stamp | This is intentionally a loose, normally non-contact clearance. State the resulting total `X` clearance explicitly in CAD; do not confuse radial clearance with total clearance. |
| Catch-guide engagement height | `4-6 mm` first prototype range | A shallow capture depth is sufficient as a side-load stop and avoids creating a long, tolerance-sensitive sliding bearing. Use generous lead-in radii and rounded stamp edges. |
| Catch-guide load rule | Must not define the normal key path, aftertouch force, or Hall position | Verify at full aftertouch with side load that contact does not appreciably change vertical end position, aftertouch feel, or Hall reading. |
| Full-aftertouch reference angles | `MWT 3.2 deg`, `MST 4.3 deg`, `QWT 5.6 deg`, `QST 7.2 deg` | Fixed user values for the geometric layout at the maximum aftertouch stop |
| Rear-guide data status | Position, zero-stop-lip clearance, and oval-tube pocket remain to be entered per key family | Use the common rear guide region about `75 mm` behind the pivot; preserve clearance between the forward-shifted stop lip and the guide package. |
| Aftertouch buffer element | `3 mm` EPDM solid round cord, about `60 Shore A` | Current first candidate for the terminal end-stop aftertouch buffer in both families |
| Buffer geometry split | `QT`: integrated into the lever geometry; `MT`: mostly housed in the raster | `MT` buffers should protrude only about `4 mm` so they do not strike too wide into the buffer |
| Buffer groove | Shallow round groove, start range `R = 4.5-5.0 mm`, `t = 1.5 mm` | Applies to the integrated `QT` lever-side buffer geometry; `MT` keeps the buffer mostly in the raster |
| Buffer retainer / contact layer | `2 mm` felt strip | Common contact layer for end stop and aftertouch onset |
| Felt state at normal key pressure | About `1 mm` compressed thickness | Defines the end of the normal playing stroke |
| Additional aftertouch reserve | About `1-1.5 mm` local cord compression | Remaining path comes from EPDM compression after the felt-defined end point |
| Reaction-group orientation at full aftertouch | Horizontal in global `XY` | The fixed reaction surface is horizontal; its normal and the intended resultant reaction force are in global `Z`. |
| Key-side stamp contact face | Horizontal at full aftertouch | Angle the key-side contact face relative to the key-top surface as required so it becomes horizontal in the full-aftertouch reference state. |
| Felt shear from normal to full aftertouch | About `0.10 mm` `MWT`, `0.12 mm` `MST`, `0.16-0.36 mm` `QWT`, `0.21-0.40 mm` `QST` | Small, controlled tangential motion in the felt layer; keep the contact face smooth and free of layer steps, seams, and sharp edges. |
| Contact-area rule | Narrow, continuous, and lightly radiused | Do not use a broad rigid clamping surface. The defined contact zone limits felt wear and permits the small angular adjustment. |
| FDM stamp print orientation | Upright, contact face horizontal and uppermost | The vertical aftertouch load acts mainly in compression through the layer stack. Use a closed, adequately thick top skin, place no support on the contact face, and orient its finishing lines along the expected felt movement when the slicer permits. |
| Geometry reference state | Full-aftertouch end position | Current layout work is now referenced to the maximum aftertouch stop rather than to the normal-travel endpoint |
| Front aftertouch reserve interpretation | Just under `2 mm` target at the key front for each key family | `MWT` is now aligned via about `11.8 mm` full front travel and about `9.8 mm` normal front travel |
| Hall sensor | `Allegro A1324LUA-T`, linear ratiometric analog, `TO-92S` | One sensor per key; continuous position signal supports velocity threshold timing and aftertouch evaluation |
| Key magnet size | Cylindrical `4 x 3 mm`, grade `N45` | Current active Hall-sensing magnet on each key |
| Hall sensor / magnet positioning | Stable local mount and per-key calibration required | The relevant tolerance is the relative position of each sensor and its own magnet; individual rest and full-travel calibration absorbs repeatable key-to-key offsets |
| Hall crosstalk prototype result | No practically visible response at `10 mm` lateral `X` magnet offset in the tested setup | Treat adjacent-magnet crosstalk as negligible for the current geometry, pending confirmation with the final sensor, magnet, and lever placement |
| Hall operating span | About `8 mm` observed useful own-magnet distance range | Current exploratory setup approaches a low calibrated signal near the far end and retains a responsive signal near the close end; verify the final full-aftertouch position remains below output saturation |
| Ferromagnetic hardware | Prefer brass or aluminium inside the local sensor / magnet zone | A steel part can redirect the own-magnet field and is not equivalent to a laterally offset neighbor magnet; retain the current `25-30 mm` rule for unverified steel hardware and validate unavoidable closer parts with an ADC comparison test |
| Hall sensor to ferromagnetic hardware clearance | `30 mm` preferred, `25 mm` minimum, centre-to-centre | Applies to steel screws, washers, frame parts, and other ferromagnetic hardware in all directions, including below the sensor; brass splints may be closer |
| Prototype material strategy | FDM first | No metal construction required in the first iteration |

What the first prototype should verify specifically:

- whether the rear zero stop gives a stable and repeatable rest height without introducing bounce
- whether the hard zero-stop rail at `Y = 285 mm` is easy enough to adjust in practice with tape/shim build-up
- whether a thin constrained solid `TPU` or `PORON` damping layer reduces noise without adding noticeable rest-height drift or hysteresis
- whether the fixed first spring set at `Y = 235 mm` gives a useful initial force spread across `MWT`, `MST`, `QWT`, and `QST`
- whether shrink-wrapped trim weights in the `255-285 mm` zone provide sufficient acoustic damping at the zero stop when weights are used
- whether the split-pin line is the correct place for the final end stop in the simplified synth branch
- whether the `3 mm` EPDM cord plus `2 mm` felt stack produces the desired compliance and noise behavior
- whether the horizontal full-aftertouch reaction surfaces keep guide and pivot drag below perception while the felt accommodates the expected sub-`0.5 mm` tangential displacement
- whether the upright-printed FDM stamp retains a smooth, step-free contact face and shows no layer separation or accelerated felt wear under repeated full-aftertouch loading
- whether the straight `2.5 mm` brass rear splint and the `5 x 4 mm` PTFE tube compressed to about `4 mm` in `X` by `6 mm` in `Y` remain low-friction, laterally controlled, and continuously engaged through normal travel and full aftertouch for all four key families
- whether the `10 mm` PTFE bearing length and `25 mm` free splint length retain adequate engagement in the QST governing case without binding, and whether the oval tube supplies the required `Y` motion without excessive `X` play
- whether the `4 deg` splint tilt centres the QST stroke in the vertical PTFE tube and keeps the remaining approximately `+/-3.6 deg` endpoint mismatch free from binding
- whether the pivot plus rear guide leaves acceptable rotation about `Y` under playing side loads; this motion is not assumed to be constrained by the rear guide alone
- whether the optional shallow aftertouch-stamp catch guide remains completely non-contact in normal use, yet limits exceptional side load without altering vertical end position, aftertouch force, or Hall signal
- whether increasing the pivot-holder wrap toward about `180 deg` gives enough stiffness in lever direction without creating assembly or friction problems with the washer-retained axle concept
- whether the locally reduced `5 mm` pivot support land in the washer zone remains stiff enough in lever direction when executed in Tough Resin
- how far the four package lanes actually need to diverge in `Y` and `Z`
- confirm the `10 mm` lateral magnet-offset crosstalk result with the final sensor, magnet, and lever arrangement, including one resting key while its nearest neighbor is at full travel
- compare the raw ADC curve with and without any steel part that must remain inside the `25-30 mm` local sensor / magnet clearance zone
- whether a spring line around `Y = 230-240 mm` gives the right return feel without too much force increase over the stroke
- whether an optional trim-mass pocket around `Y = 255-285 mm` is sufficient if balancing mass is needed later
- whether a single `5 g` trim weight at about `Y = 275 mm` produces a useful feel change without over-biasing the low-force action

## Phase 3: Verify Hall Sensor And Aftertouch Package

This phase validates the sensing and terminal-stop package on the representative
key mechanism from phase 2 before its geometry is propagated across an octave.

- establish the initial `3.0 mm` nominal Hall sensor / magnet gap at full
	aftertouch; it is a prototype target, not an unverified absolute minimum
- record each key's raw rest, normal-travel, and full-aftertouch values; retain
	adequate ADC headroom at the close end and use per-key calibration for
	repeatable geometric offsets
- confirm the observed useful own-magnet span of about `8 mm` with the final
	leverage and sensor holder
- repeat the `10 mm` lateral-offset neighbor test and test the `QWT E/F`
	worst-case pair with one key at rest and its neighbor at full travel
- compare raw ADC curves with and without unavoidable ferromagnetic hardware
	inside the current `25-30 mm` sensor-clearance region
- verify that the `3 mm` EPDM cord and `2 mm` felt transition produces a
	musically useful normal-stroke endpoint and aftertouch reserve without
	perceptible friction, instability, or unwanted guide loading

The phase is complete only when the chosen mechanical sensor position gives a
monotonic, repeatable, nonsaturating position curve across rest, normal travel,
and full aftertouch.

## Phase 4: Derive Quarter-Tone Integration For The Synth Branch

Transfer the phase-2 and phase-3 findings to `QWT` and `QST` without treating
the quarter-tone keys as simplified plungers or merely shortened main keys.

- finalize the `QWT` and `QST` lever, spring, weight, guide, buffer, and sensor
	positions from the shared pivot baseline
- enter the guide reference points and nominal radii per key family; preserve
	the same functional radius for the brass splint and PTFE tube
- verify continuous radial-guide engagement with the required `3-5 mm` end
	reserve and sufficient reinforced wall thickness at the narrow QT bushing
	zone
- verify the horizontal full-aftertouch contact geometry and its limited felt
	shear for both QT families
- compare normal travel, return force, aftertouch onset, and perceived control
	with the validated MWT/MST reference rather than seeking identical geometry

## Phase 5: Build One-Octave Mock-Up

Build a representative one-octave mechanical module with all four key families
and their intended package lanes. This exposes interference and consistency
problems that single-key testing cannot reveal.

- verify Kassel raster, player-side gaps, pivot spacing, radial-guide clearance,
	and access for assembly and service
- test adjacent-key mechanical independence and the final worst-case Hall
	crosstalk arrangement under realistic spacing
- verify repeatability of rest height, normal travel, aftertouch endpoint, and
	return feel across the octave rather than only on one selected key
- establish the practical sensor-group harness route, supply-injection points,
	and mux-board location for the phase-6 electronics prototype

## Phase 6: Electronics Prototype and Firmware Scan Baseline

The first electronics prototype uses a complete representative sensor group
before committing to the `122`-key wiring harness or a sensor-local PCB.

| Field | Initial value | Prototype rule |
|---|---|---|
| Real-time controller | `Teensy 4.1` | Sensor scan, key-state evaluation, USB-MIDI, and 5-pin DIN remain local real-time tasks. A later Raspberry Pi may handle higher-level protocol or sound-control work, but must not determine scan timing. |
| Hall sensor | `Allegro A1324LUA-T` | One ratiometric analog sensor per key, powered from the analog sensor rail and read as a calibrated position signal. |
| Multiplexer topology | `8 x CD74HC4067`, 16:1 | Each mux serves up to 16 Hall outputs. Their four address lines are common; all eight mux outputs are acquired in parallel on eight separate Teensy ADC inputs. |
| Channel count | `122` | Eight address positions acquire `8 x 16 = 128` possible channels. Six unused inputs must be tied to a defined quiet analog level or otherwise handled explicitly in firmware; do not leave them floating. |
| Address-block timing | Read address `n`, immediately set `n + 1`, process and queue block `n` while block `n + 1` settles, then read `n + 1` | The common address cannot advance between individual mux-output reads. One address block is therefore the atomic scan unit. |
| Initial address-settling allowance | About `90 us` | Deliberately conservative first value. It covers mux switching, sensor-output/wiring settling, and ADC sample-and-hold acquisition; reduce only after raw-data measurements show no address residue or timing-sensitive noise. |
| Hall-output capacitors | None initially | Do not add output-to-ground RC capacitors before measurement. They can increase the selected channel's settling time and make dynamic position measurements less representative. |
| Group supply bulk decoupling | `10 uF` at each physical supply-injection end of a group | Baseline against wiring resistance and low-frequency supply movement; placement follows the actual group harness, not an arbitrary sensor count. |
| Group supply ceramic decoupling | `100 nF` at the mux/group supply injection, plus the far end for a long group harness | This remains necessary even with a long analog mux settling period; it controls local high-frequency VCC/GND impedance rather than selected-channel settling. |
| Sensor-local capacitors | None initially | Add only when a complete-group measurement identifies a local supply-noise problem that group-end decoupling cannot control. |
| Data transport | Buffered and non-blocking | USB logging, MIDI transmission, or later serial forwarding must not delay the periodic address-block scan. |

The `90 us` allowance is a signal-settling budget, not a substitute for supply
decoupling. It is specifically a reason to avoid speculative Hall-output RC
filtering, not to omit the small group-level supply capacitors.

The electronics prototype must log raw ADC blocks while keys move and compare
address-settling allowances of approximately `10`, `20`, `40`, `60`, and
`90 us`. For each setting, record rest noise, channel-to-channel residue after
an address change, repeatability, full-travel headroom, and supply ripple. Test
the baseline group-end capacitors first; add local ceramics only for an observed
failure mode. Retain the shortest interval that is clean across a full group
with its intended cable length and scan load.

## Preserved Technical Decisions

The following remain active independent of the mechanical branch change:

- Kassel quarter-tone layout
- one Hall sensor per key
- Teensy-based real-time scanning front-end
- USB-MIDI and 5-pin DIN in phase 1
- elastomer-based aftertouch reserve rather than FSR force sensing

## Mechanical Tasks Now Considered Closed in the Active Root

The following topics are no longer maintained in this active build guide because they belong to the archived branch:

- piano-like main-key pivot geometry around the archived long-lever proportion
- archived QT pivot package derived from the deeper action family
- MP5-based proportional reference as an active anchor

These remain available only in `docs/archive/SteinwayLike/`.

## CAD Repository Structure And Link Rules

The CAD repository is organized by document role rather than by a prematurely fixed manufacturing process. A primary `.FCStd` document is kept directly in its role directory. Its exports, previews, spreadsheets, and other supporting data are kept in a same-named subdirectory.

Target structure:

```text
docs/CAD/
├─ Master.FCStd
├─ Master/
│  └─ global spreadsheet exports, reference data, and previews
├─ Design/
│  ├─ Keys.FCStd
│  ├─ Keys/
│  │  ├─ MasterLayout.csv
│  │  └─ KeysPreview.FCStd
│  ├─ PivotYZ.FCStd
│  ├─ LeverEnvelope.FCStd
│  ├─ ReactionGroupYZ.FCStd
│  └─ Controls.FCStd
├─ Assemblies/
│  ├─ QTKB_Current.FCStd
│  ├─ QTKB_OneOctave.FCStd
│  └─ Production/
├─ BuildParts/
├─ BoughtParts/
└─ STPs/
```

Role definitions:

- `Master.FCStd` holds global, technology-independent reference geometry and scalar parameters. Its spreadsheet must not contain references to bodies, features, or assemblies.
- `Design/` holds functional design documents. `PivotYZ.FCStd` is the first YZ-space study for the pivot, lever bearing, and rear zero stop; it is not yet a released part.
- A same-named data directory belongs to its primary document. For example, `Design/Keys/MasterLayout.csv` is the data export for `Design/Keys.FCStd`; `KeysPreview.FCStd` remains with the key-design data because it is not a system-level assembly.
- `Assemblies/` holds linked system views, collision and packaging checks, and later production assemblies. `QTKB_Current.FCStd` is the current visible system state, not an authoring source for upstream geometry.
- `BuildParts/` holds concrete part documents without separating them by process or maturity. Manufacturing method, material, quantity, and revision are assigned later by a production assembly rather than by moving the master part document.
- `BoughtParts/` holds CAD representations of purchased components needed for placement, clearance, and assembly checks.
- `STPs/` holds neutral exchange and fabrication exports only; it does not become a second editable source for a part.

FreeCAD dependency rules:

- allowed dependency direction: `Master -> Design -> BuildParts -> Assemblies`
- `Master.FCStd` must not reference `Design`, `BuildParts`, or `Assemblies`
- assemblies may reference upstream documents but must not reconfigure their source spreadsheets through Tracking Links
- global spreadsheets carry scalar data only; family-local spreadsheets may contain links only to objects within the same family document
- after a document has external links, avoid moving or renaming it; create a named design study for alternatives instead

## CAD Naming Conventions

Names identify the owning domain and role rather than relying on generic labels such as `Spreadsheet`, `Body001`, or `MasterLayout` outside its key-layout context. Once a name is used by an external link or an expression, keep that name stable.

- primary document: `<Domain>.FCStd`, for example `Master.FCStd`, `Keys.FCStd`, `PivotYZ.FCStd`, and `Controls.FCStd`
- supporting-data directory: `<DocumentName>/`, for example `Keys/` for `Keys.FCStd` and `Master/` for `Master.FCStd`; it holds exports, previews, and document-local data
- preview document: `<Domain>Preview.FCStd`, for example `KeysPreview.FCStd`; a preview remains with the supporting data of its design document unless it becomes a multi-document system assembly
- system assembly: `QTKB_<Scope>.FCStd`, for example `QTKB_Current.FCStd` and `QTKB_OneOctave.FCStd`
- design study: `<Domain>_<Purpose>.FCStd`, for example `PivotYZ.FCStd`, `LeverEnvelope.FCStd`, and `ReactionGroupYZ.FCStd`
- document names carry no object-type prefix; use CamelCase descriptive names, for example `PivotZeroStopYZ.FCStd`, `Keys.FCStd`, and `Master.FCStd`
- FreeCAD Part object: `p<Name>`, for example `pPivotReference` and `pZeroStopReference`
- FreeCAD Part container: `pc<Name>`, for example `pcPivotZeroStopYZ`; use `pc` rather than `p` where the object exists primarily to group child objects
- FreeCAD Body object: `b<Name>`, for example `bMWT`, `bMST`, `bQWT`, `bQST`, and `bPivotCradle`; do not rely on automatically assigned names such as `Body001`
- FreeCAD Sketch object: `s<Name>`, for example `sPivotAxisYZ`, `sZeroStopYZ`, and `sLeverEnvelopeYZ`
- FreeCAD Spreadsheet object: `t<Name>`, for example `tMasterGlobals`, `tKeysLayout`, `tKeysMWT`, `tKeysMST`, `tKeysQWT`, and `tKeysQST`
- FreeCAD Link object: `l<Name>`, for example `lMWT`, `lPivotAxisYZ`, and `lZeroStopReference`
- parameter alias: use the shortest unambiguous technical name, for example `OctaveWidth`, `PivotX`, `PivotY`, `PivotZ`, `MWT_HeadWidth`, and `QWT_StartY`
- add a family, domain, or role prefix only when it distinguishes otherwise ambiguous values. Do not add a prefix merely because the value is part of a spreadsheet; for example, prefer `PivotY` to `Coord_PivotY`.
- use `X`, `Y`, and `Z` only as coordinate suffixes. Keep units in the property type or spreadsheet cell; do not encode units in names.
- use `Master` only for the owner-level integration table or document. A domain-specific key-layout table is `tKeysLayout`; do not call it merely `MasterLayout`.

Spreadsheet scope rule:

- `tMasterGlobals` grows only when a scalar is a system reference or is needed by more than one independent design document.
- a downstream spreadsheet receives a master scalar through a local expression, for example `tKeysLayout.PivotY = tMasterGlobals.PivotY`.
- local formulas and bodies reference that local alias, for example `tKeysLayout.PivotY`, rather than repeatedly reaching into `tMasterGlobals`.
- this local alias is an expression-backed interface, not a copied numerical value.

## Documentation Rule

`MasterLayout.csv` and later equivalent CAD exports are authoritative for detailed parameterized geometry. This build guide records the active design decisions and the values needed to interpret or build from that geometry. Update both in the same workstream when an active decision changes.

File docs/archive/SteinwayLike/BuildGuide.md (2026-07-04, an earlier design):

# Quarter-Tone Keyboard – Build Guide

> **Status:** In preparation. This document is built up in parallel with the research and design phase.  
> Decisions from `Research.md` flow into concrete build steps here.
>
> **Update (June 2026):** The detailed geometry currently documented below represents the archived `Steinway-like` intermediate branch. It is retained as a reference snapshot while the active layout work switches to a synthesizer / semi-weighted direction with Access Virus C / Fatar feel as the new anchor.

> **Archived naming note:** `VT` is the older archive label for what the active branch now calls `QT`. This document predates the active four-family naming `MWT`, `MST`, `QWT`, `QST`.

---

## Build Phase Overview

| Phase | Content | Status |
|---|---|---|
| 1 | Finalize layout & mechanical concept | Open |
| 2 | Mock-up / Proof of Concept | Open |
| 3 | Electronics prototype | Open |
| 4 | Firmware (MIDI, velocity, controllers) | Open |
| 5 | Mechanical series production (printing + woodwork) | Open |
| 6 | Electronics final version | Open |
| 7 | Integration & housing | Open |
| 8 | Test, calibration, stage test | Open |

---

## Phase 1: Layout & Mechanical Concept

### 1.1 Layout Decision

Decided:

- Layout based on Kassel Principle (Organ St. Martin)
- Base keyboard: 61 keys (5 octaves + 1 C)
- Quarter-tone extension as a second, height-offset key structure behind the base keys

To document:
- Chosen keyboard variant with rationale
- Sketches / CAD drawings
- Octave width and key dimensions for the quarter-tone keys

### 1.2 Tools & Materials (Phase 1)

- Cardboard / foam for quick mock-up
- Calipers, angle gauge
- Optionally: first FDM test print of one octave

### 1.3 Reference Geometry Table: Normal Keyboard

This section fixes the baseline reference system for the standard keyboard geometry. Quarter-tone key geometry will be added later as a separate variant.

#### Coordinate System

- Origin `O = (0, 0, 0)`: front top edge of the white key in rest position
- `x`: lateral direction across the keyboard
- `y`: positive toward the rear of the keyboard
- `z`: positive upward
- Positive rotation `theta`: key nose moves downward in side view

#### Fixed Reference Points and Kinematics

| Item | y (mm) | z (mm) | theta (deg) | Status | Note |
|---|---:|---:|---:|---|---|
| White key front top edge, rest position (`O`) | 0.0 | 0.0 | 0.00 | Fixed | Global reference point |
| Hall sensor center on frame | <=35.0 | open | 0.00 | Partial | Must satisfy minimum 25 mm distance to guide pin at `y = 60 mm` |
| Front end-stop contact zone on frame | <=35.0 | -43.0 | 0.00 | Partial | Front felt/Kapton first-contact zone associated with the Hall sensor pocket; current first-contact level |
| PORON buffer zone on frame | 35.0-60.0 | open | 0.00 | Partial | Recessed compression zone behind the front end stop and ahead of the guide pin |
| Aftertouch hard end on frame | 35.0-60.0 | -46.0 | 0.00 | Partial | Current hard endpoint of the front aftertouch zone |
| Front guide pin on frame | 60.0 | open | 0.00 | Fixed | Preferred guide-pin position for the normal keyboard front zone |
| Main-key pivot axis | 210.0 | -24.0 | 0.00 | Fixed | User-defined baseline |
| Return spring attachment point on frame | 228.0 | open | 0.00 | Recommended | Current prototype spring concept: anchor about `18 mm` behind the main-key pivot; paired with `20 mm x 0.5 mm` spring, about `23 mm` installed length at zero position |
| Zero-position stop on frame | 280.0 | open | 0.00 | Partial | Frame-side rest stop fixed in `y`; `z` to be defined after key geometry settles |
| White key front top edge, bottom stop | 0.0 | -10.8 | 2.95 | Fixed | Pure geometric bottom-stop reference, excluding elastic compression and trapped-air effects |
| Black key front start | 51.0 | open | 0.00 | Partial | Front geometric start of the black key including air gap |
| Black key top reference plane, rest position | 53.5 | 12.0 | 0.00 | Fixed | Upper front edge shifted 2.5 mm rearward from black-key start due to front chamfer and gap |
| Black key top reference plane, bottom stop | 53.5 | 2.0 | 3.66 | Fixed | Pure geometric bottom-stop reference, excluding elastic compression and trapped-air effects |

Rotation derivation for the white-key front point:

```text
theta_white = asin(10.8 / 210) = 2.95 deg
theta_black = asin(10.0 / (210 - 53.5)) = asin(10.0 / 156.5) = 3.66 deg
```

#### Reference Rotation Angle Table

This table lists the currently fixed standard-key rotation cases. It uses the same reference points as the geometry table above.

| Key / reference point | Effective lever arm (mm) | Travel at reference point (mm) | Rotation angle (deg) | Use case |
|---|---:|---:|---:|---|
| White key, front top edge | 210.0 | 10.8 | 2.95 | Standard white-key play travel |
| White key, front top edge | 210.0 | `10.8 + 4.03 = 14.83` | `2.95 + 1.10 = 4.05` | Current white-key aftertouch construction state with front first contact at `z = -43 mm` and aftertouch hard end at `z = -46 mm` |
| Black key, top reference plane at `y = 53.5 mm` | 156.5 | 10.0 | 3.66 | Standard black-key front reference |
| Black key, top reference plane at `y = 53.5 mm` | 156.5 | `10.0 + 3.0 = 13.0` | `3.66 + 1.10 = 4.76` | Current black-key aftertouch construction state with front first contact at `z = -43 mm` and aftertouch hard end at `z = -46 mm` |

Bottom-stop values in this table are hard-geometry reference points only. Felt, PORON/elastomer compression, and any trapped-air spring effect are handled separately in the play/clearance budget.

Current front-zone aftertouch increment: from first contact at `z = -43 mm` to aftertouch hard end at `z = -46 mm`, the additional rotation is currently taken as about `1.1 deg`.

Separate CAD rule: the global normal-key design ceiling remains `theta_max = 5.0 deg` for pocket, guide-slot, and clearance dimensioning. It is not a target playing angle; it is only an upper design limit.

Front-zone order in positive `y` direction is currently fixed as: front felt end stop + Hall sensor pocket -> recessed PORON damping zone -> front guide pin.

With guide pin `y = 60 mm` and minimum guide pin to Hall sensor center distance of `25 mm`, the Hall sensor center must satisfy `y <= 35 mm`.

#### Fixed Scalar Dimensions (Normal Keyboard)

| Parameter | Value (mm) | Status | Note |
|---|---:|---|---|
| Octave width | 165.0 | Fixed | 7 white keys |
| White key width at front | 23.6 | Fixed | Head width |
| White key visible length | 150.0 | Fixed | Front section to case line |
| White key front travel | 10.8 | Fixed | Measured / standard reference |
| White key rear travel | 5.0 | Fixed | Measured |
| Black key width | 12.5 | Fixed | Base width |
| Black key visible length | 95.0 | Fixed | Standard reference used in docs |
| Black key height above white plane | 12.0 | Fixed | Rest position |
| Black key front travel | 10.0 | Fixed | Standard reference |
| Maximum rotation angle, all keys/pockets | 5.0 deg | Fixed | Global design limit for pocket and guide clearance |

#### Open Items for the Next Geometry Pass

- Exact `z` coordinate and final chosen `y` coordinate of Hall sensor center within `y <= 35 mm`
- Exact `z` coordinate and final chosen `y` coordinate of the front end-stop contact zone within `y <= 35 mm`
- Exact `z` coordinate and final chosen `y` range of the PORON buffer zone within `35 mm < y < 60 mm`
- Final guide-pin `z` coordinate and required PTFE-slot clearance at `theta_max = 5 deg`
- Exact `z` coordinate of the frame-side return spring attachment point
- Exact `z` coordinate of the frame-side zero-position stop
- Exact `z` reference location for black-key front start
- Reference point(s) for rear white-key geometry relative to the pivot
- Equivalent table for the quarter-tone keyboard variant

### 1.4 Reference Geometry Table: Quarter-Tone Keyboard

This section starts the same reference system for the VT keyboard variant. Coordinates remain referenced to the front top edge of the white key in rest position.

#### Fixed Reference Points and Kinematics

| Item | y (mm) | z (mm) | theta (deg) | Status | Note |
|---|---:|---:|---:|---|---|
| VT front top edge above whole-tone keys, rest position | 90.0 | 12.0 | 0.00 | Fixed | Front exposed VT edge in the white-key VT row |
| VT front top edge above semitone keys, rest position | 120.0 | 23.5 | 0.00 | Fixed | Front exposed VT edge in the black-key VT row |
| VT front top edge above whole-tone keys, 10 mm target hub | 90.0 | 2.0 | 3.70 | Fixed | Targeted to match the normal black-key front travel |
| VT front top edge above semitone keys, 10 mm target hub | 120.0 | 13.5 | 4.59 | Fixed | Targeted to match the normal black-key front travel; dimensioning VT case |
| VT pivot axis | 245.0 | 10.0 | 0.00 | Recommended | Preferred packaging anchor; gives clear separation from the main-key pivot and more room for the VT tail geometry |
| VT rear guide pin on frame | 290.0 | open | 0.00 | Recommended | Guide pin enters from below; about 45 mm behind the VT pivot for a more stable guidance lever arm |
| VT return spring attachment point on frame | 263.0 | open | 0.00 | Recommended | Current prototype spring concept: anchor about `18 mm` behind the VT pivot; paired with `20 mm x 0.4 mm` spring, about `25 mm` installed length at zero position |
| VT counterweight center | 305.0 | open | 0.00 | Open / to be rechecked | Previous start value; exact `y` must be rechecked after the VT aftertouch package is shifted rearward |
| VT upper buffer / aftertouch zone on frame ceiling | 370.0 | open | 0.00 | Recommended | New common VT PORON / aftertouch target, dimensioned from the semitone row for about `1:1` local-to-front travel there |
| VT rear end-stop zone on frame ceiling | 380.0 | open | 0.00 | Recommended | Harder end-stop package behind the relocated VT aftertouch zone |
| VT upper Hall sensor zone on frame ceiling | 390.0 | open | 0.00 | Recommended | Common sensor package behind the relocated rear end stop; keeps the former about `20 mm` offset behind the VT aftertouch zone |

Geometry check at recommended `VT pivot = (245, 10)`:

```text
delta_main_to_vt_y = 245 - 210 = 35 mm
delta_main_to_vt_z = 10 - (-24) = 34 mm
axis_distance = sqrt(35^2 + 34^2) = 48.8 mm

lever_whole = 245 - 90 = 155 mm
lever_semitone = 245 - 120 = 125 mm

hub_whole_at_5deg = 155 * sin(5 deg) = 13.5 mm
hub_semitone_at_5deg = 125 * sin(5 deg) = 10.9 mm

theta_whole_for_10mm = asin(10 / 155) = 3.70 deg
theta_semitone_for_10mm = asin(10 / 125) = 4.59 deg

guide_travel_at_y290_whole = (290 - 245) * sin(3.70 deg) = 2.90 mm
guide_travel_at_y290_semitone = (290 - 245) * sin(4.59 deg) = 3.60 mm

spring_travel_at_y263_whole = (263 - 245) * sin(3.70 deg) = 1.16 mm
spring_travel_at_y263_semitone = (263 - 245) * sin(4.59 deg) = 1.44 mm

buffer_travel_at_y370_whole = (370 - 245) * sin(3.70 deg) = 8.06 mm
buffer_travel_at_y370_semitone = (370 - 245) * sin(4.59 deg) = 10.00 mm

front_travel_from_3mm_buffer_whole = 3.0 * (155 / 125) = 3.72 mm
front_travel_from_3mm_buffer_semitone = 3.0 * (125 / 125) = 3.00 mm

end_stop_travel_at_y380_whole = (380 - 245) * sin(3.70 deg) = 8.70 mm
end_stop_travel_at_y380_semitone = (380 - 245) * sin(4.59 deg) = 10.80 mm

sensor_travel_at_y390_whole = (390 - 245) * sin(3.70 deg) = 9.35 mm
sensor_travel_at_y390_semitone = (390 - 245) * sin(4.59 deg) = 11.60 mm

pin_to_sensor_clearance = 390 - 290 = 100 mm
```

Implication: `VT pivot = (245, 10)` is the better first packaging anchor if the required pivot-to-pivot clearance must exceed `40 mm`. It gives about `48.8 mm` center-to-center axis spacing relative to the normal-key pivot at `(210, -24)`. The consequence is explicit: VT key geometry is now substantially different from the normal keys, with longer effective front lever arms and mirrored sensing/aftertouch moved behind the pivot on the upper frame.

Design rule for the current VT variant: both VT key types target the same `10.0 mm` front travel as the normal black keys. The resulting required rotation angles are `3.70 deg` for the VT row above whole tones and `4.59 deg` for the VT row above semitones. The global `theta_max = 5.0 deg` still provides about `0.41 deg` reserve in the dimensioning semitone VT row.

Practical guide-pin placement rule: start the VT guide pin around `y = 290 mm`. This places the guide about `45 mm` behind the VT pivot, which is a better compromise between guidance leverage and easy insertion from below than the earlier compact zone near the pivot.

Corrected VT buffer placement rule: use the VT semitone row as the dimensioning case and relocate the common VT PORON / aftertouch zone to about `y = 370 mm`. This gives about `1:1` local-to-front travel for the VT semitone row and about `1.24:1` for the VT whole-tone row, which is a much more plausible common compromise than the earlier short rear package.

With `3.0 mm` local PORON compression at `y = 370 mm`, the expected front aftertouch travel becomes about `3.00 mm` on the VT semitone row and about `3.72 mm` on the VT whole-tone row.

Practical end-stop placement rule: if the translated VT package keeps the previous about `10 mm` spacing from aftertouch zone to firmer terminal stop, place the VT harder rear end stop at about `y = 380 mm`.

Practical sensor placement rule: if the translated VT package keeps the previous about `20 mm` offset from aftertouch zone to Hall sensor center, place the common VT Hall sensor package at about `y = 390 mm`. This gives about `9.35 mm` sensor travel for the VT row above whole tones and about `11.60 mm` for the VT row above semitones, while increasing guide-pin to Hall-sensor spacing to about `100 mm`.

Practical counterweight placement rule: the earlier start value around `y = 305 mm` is no longer automatically tied to the middle of the VT rear package. Counterweight `y` must be rechecked after the translated VT aftertouch package and the resulting pivot-section geometry are fixed.

Practical return-spring placement rule: current prototype concept places the VT frame-side spring anchor around `y = 263 mm`, about `18 mm` behind the VT pivot. This keeps the spring very close to the pivot so spring force changes only weakly over the key stroke; current preferred VT spring is `20 mm x 0.4 mm` with about `25 mm` installed length at zero position.

Updated VT rear package order in positive `y`: guide pin -> felt / PORON buffer (`y ~ 370 mm`) -> rear end stop (`y ~ 380 mm`) -> Hall sensor (`y ~ 390 mm`).

The earlier assumption that the VT rear damper geometry could directly reuse the main-key felt/PORON stack is no longer accepted as a baseline. The VT aftertouch geometry must now be dimensioned from the semitone-row lever arm, while the VT pivot-section cross-section must be recalculated for the translated package.

Minimum fallback: `VT pivot = (240, 10)` still gives `45.3 mm` axis spacing and remains plausible if later CAD shows that `245 mm` is not required.

#### VT Rear Sensor / Damper Geometry Table

This table records the current recommended VT package order behind the pivot.

| Element | Longitudinal position | Thickness / level | Current decision | Function |
|---|---|---|---|---|
| VT return spring attachment point | `y = 263 mm` | open | Recommended | Frame-side spring anchor, about `18 mm` behind the VT pivot |
| VT rear guide pin | `y = 290 mm` | open | Recommended | Guidance point, inserted from below |
| VT counterweight center | `y = 305 mm` | open | Open / to be rechecked | Previous balancing-mass start value; no longer coupled to the middle of the translated VT aftertouch package |
| VT felt support / first contact layer | `y = 370 mm` | `2.0 mm` felt | Recommended | Common semitone-dimensioned VT first-contact and substrate level |
| VT PORON aftertouch layer | `y = 370 mm` | `4.0 mm` PORON, exact recess open | Recommended | Common VT aftertouch zone; target about `1:1` local-to-front travel on the VT semitone row |
| VT PORON deeper tuning option | `y = 370 mm` | recess and stack tuning open | Open | To be tuned after the translated VT package and feel target are verified |
| VT rear end-stop zone | `y = 380 mm` | harder felt / elastomer stop | Recommended | Defines the firmer terminal stop behind the relocated aftertouch zone |
| VT Hall sensor package center | `y = 390 mm` | Ceiling-mounted package | Recommended | Common analog position sensing zone behind the relocated VT end stop |
| Pin-to-sensor clearance | `290 mm` to `390 mm` | `100 mm` in `y` | Fixed by translated package | Strong magnetic clearance reserve to the steel guide pin |

#### VT Sensor Rail / Reaction Rail Split (Interim)

- Current preferred VT architecture separates the non-force sensor rail from the force-bearing reaction rail.
- Lower VT sensor rail:
	- sits directly under the keys where packaging allows
	- should be adjustable and service-friendly
	- current preferred carrier is a `20 x 20 mm` aluminium mounting profile (KLAK20 or equivalent)
	- sensor-side mounting hardware in this zone should preferably be brass or aluminium rather than steel
	- current preferred fastening concept in this zone: printed nut stones / sliding inserts for the KLAK20 slot with embedded brass nuts
	- floating / guided 3D-printed inserts may clip into this profile
- Upper VT reaction rail:
	- carries buffer, end stop, and any upper guidance load
	- must be substantially stiffer than the elastomer stack itself
	- current preferred carrier is a `16 x 16 mm` steel square profile
- Design consequence: Hall sensors no longer need to share the same structural package as the VT force path. Full travel can still be measured if the upper reaction rail is stiff and correctly referenced.

#### Sensor Environment Rules (Interim)

- Keep steel guide pins at least `25 mm` from Hall sensor centres; `30 mm` is now the preferred practical minimum where packaging allows.
- Keep Hall sensors and magnet paths away from external ferromagnetic surroundings.
- Brass is acceptable in direct sensor proximity for brackets, threaded inserts, spacers, and mounting screws; current preferred rule for the KLAK20 sensor-side mount is brass/aluminium hardware instead of steel.
- Practical current implementation: use printed KLAK20 nut stones with embedded brass nuts rather than steel T-nuts in the sensor-side mounting zone.
- Current enclosure rule: keep at least `30 mm` from Hall sensor / magnet path to the outer housing skin in zones where steel stands, brackets, or other ferromagnetic parts can approach; `40 mm` is preferred in especially exposed zones.
- Avoid placing transformers, large power supplies, loudspeaker magnets, or similar magnetic sources directly under or on the keyboard.
- The upper steel VT reaction rail is acceptable because it is mechanically useful and can be kept well separated from the Hall sensor rail.

#### Prototype Return Spring Table

This table records the current shared near-pivot spring concept for both key families.

| Key family | Spring anchor position | Distance behind pivot | Prototype spring | Installed length at zero position | Additional spring extension over full front travel |
|---|---|---:|---|---:|---|
| Main keys | `y = 228 mm` | `18 mm` | `20 mm x 0.5 mm` tension spring | `23 mm` | about `0.93 mm` |
| VT keys above whole tones | `y = 263 mm` | `18 mm` | `20 mm x 0.4 mm` tension spring | `25 mm` | about `1.16 mm` |
| VT keys above semitone keys | `y = 263 mm` | `18 mm` | `20 mm x 0.4 mm` tension spring | `25 mm` | about `1.44 mm` |

#### Open Items for the Next Geometry Pass

- Exact `z` coordinate and insertion geometry of the VT rear guide pin from below
- Exact `z` positions of the VT Hall sensor package and the felt / PORON contact region behind the VT pivot
- Frame clearances between VT tail geometry and the reinforced main-key pivot beam

---

## Phase 2: Mock-up / Proof of Concept

### 2.1 Goal

Test the playability of the layout physically. The pianist should be able to grip the mock-up and give feedback **before** complex manufacturing parts are produced.

### 2.2 Mock-up from FDM Print

*Detailed steps follow after layout decision.*

To document:
- Print parameters (material, resolution, infill)
- File paths of STL/CAD files
- Adjustments based on feedback

---

## Phase 3: Electronics Prototype

### 3.1 Bill of Materials

#### Electronics

| Component | Qty | Specification | Source | Unit price | Total |
|---|---|---|---|---|---|
| Microcontroller | 1 | Teensy 4.1 | PJRC / Mouser | ~€30 | €30 |
| System / control MCU | 1 | ESP32 module (current preferred control/calibration layer) | Mouser / AliExpress | ~€8 | €8 |
| Hall sensor | 150 | A1324LUA-T, TO-92S | AliExpress / Mouser | ~€0.36 | €54 |
| Multiplexer | 8 | CD74HC4067, 16:1 analog | Reichelt / AliExpress | ~€0.50 | €4 |
| External ADC for slow controls | 1 | MCP3204 / MCP3208 or equivalent (optional, preferred for expression inputs on second controller) | Mouser / Reichelt | ~€4 | €4 |
| Bypass capacitor | 200 | 100 nF, 0603 SMD | Reichelt | ~€0.02 | €4 |
| RC filter resistor | 10 | 1 kΩ, 0603 SMD | Reichelt | ~€0.02 | €0.20 |
| RC filter capacitor | 10 | 10 nF, 0603 SMD | Reichelt | ~€0.02 | €0.20 |
| 5-pin DIN MIDI socket | 1 | Standard DIN 41524 | Reichelt | ~€1 | €1 |
| Pitchbend potentiometer | 1 | Alps RK09D or similar | Mouser | ~€2 | €2 |
| Volume/Expression pot | 1 | Alps RK09D or similar | Mouser | ~€2 | €2 |
| Prototype PCBs | 2–3 | Stripboard 160×100 mm | Reichelt | ~€2 | €6 |
| Final PCBs | 10–12 | Octave module PCB, custom design | JLCPCB / PCBWay | ~€5/ea | €60 |

#### Mechanics

| Component | Qty | Specification | Source | Unit price | Total |
|---|---|---|---|---|---|
| Neodymium magnet | 150 | Ø4×2 mm, N45 | Supermagnete.de | ~€0.15 | €23 |
| Pivot pin | 6 | Ø4 mm steel, ~175 mm | Per meter, metal supplier | ~€1/m | €6 |
| Front guide pin | 122 | Nail drill Ø2 mm, HSS, ~28 mm | Set of 50 | ~€0.10 | €12 |
| PTFE guide tube | 1 m | Ø4/2 mm | AliExpress / Conrad | ~€2/m | €2 |
| Tension spring | 130 | Prototype set: free length about `20 mm`, body Ø about `4 mm`, wire Ø `0.4 mm` for VT and `0.5 mm` for main keys | Gutekunst Federn | ~€0.30 | €39 |
| Lead weight | 122 | ~15–20 g/key (fishing lead or similar) | Fishing supplies | ~€0.20 | €25 |
| ASA filament | ~1 kg | For key blanks FDM | Prusament / Fillamentum | ~€25/kg | €25 |
| Tough Resin | ~0.5 l | For frame modules SLA | Formlabs / Phrozen | ~€50/l | €25 |
| Flexible Resin | ~0.2 l | For elastomer stops SLA | Formlabs Elastic 50A or similar | ~€60/l | €12 |
| Piano felt strip | 2 m | 2.0 mm dense felt, adhesive-backed preferred | Piano supply / felt supplier | ~€4/m | €8 |
| PORON sheet | 1 | 4 mm polyurethane microcellular foam sheet | Keyboard mod supplier / industrial foam supplier | ~€8 | €8 |
| Kapton tape | 1 roll | 50–100 µm, electrical/mechanical sensor isolation | Electronics supplier | ~€3 | €3 |
| Contact adhesive | 1 | Rubber/foam compatible (for felt/PORON bonding) | Hardware store | ~€8 | €8 |
| Plywood 10 mm | 1 sheet | Birch BB, 1200×600 mm | Hardware store | ~€15 | €15 |
| Aluminium angle profile | 2 m | 15×15×2 mm | Metal supplier | ~€3/m | €6 |
| Adjustable aluminium profile | 2 m | KLAK20 / 20×20 mounting profile | Aluminium profile supplier | ~€6/m | €12 |
| Steel square profile | 2 m | 16×16 mm | Metal supplier | ~€4/m | €8 |
| White piano key covers | 62 | Standard size 50×23 mm | Piano parts supplier | ~€1 | €62 |

#### Total Estimate (test bench + complete keyboard)

| Category | Estimate |
|---|---|
| Electronics | ~€177 |
| Mechanics | ~€299 |
| **Total** | **~€476** |

*Prices excluding shipping. Quantities for 5 octaves + 1 C (61 base + 61 VT = 122 keys). ~20% reserve included.*

### 3.2 Schematic

*To follow.*

### 3.3 Assembly

*To follow.*

### 3.4 Main-Key Aftertouch Stack (Prototype Decision)

For the normal-tone keybed (main keys), the aftertouch stack is placed at the front key zone.

- Hall sensor is mounted in a front frame pocket (about 8 mm deep region).
- Sensor is covered with 2-layer Kapton tape (50–100 µm each).
- Mechanical load path is carried by the surrounding frame geometry, not by the sensor package.
- First contact/end-stop layer: 2.0 mm dense piano felt.
- Hall sensor pocket and front end-stop share the same front zone in `y`.
- Behind the front stop, add a second compression zone: PORON strip, 4 mm thick, recessed by 2 mm.
- PORON sits on the same 2.0 mm felt layer that is used as the front end damping layer.
- This creates a direct felt-to-PORON top transition without a step in the contact path.
- Front guide pin target position: `y = 60 mm`.
- Guide pin is placed only after this damping zone.
- Minimum guide pin to Hall sensor center distance: 25 mm.
- Derived constraint: Hall sensor center must lie at `y <= 35 mm`.
- Front-zone order in `y`: front felt end stop + Hall sensor pocket -> recessed PORON -> guide pin.

#### Main-Key Aftertouch / Damper Geometry Table

This table records the current front-zone prototype geometry for the main keys.

| Element | Longitudinal size / position | Thickness / level | Current decision | Function |
|---|---|---|---|---|
| Hall sensor pocket | Front zone, within `y <= 35 mm` | Pocket depth about 8 mm | Fixed as local sensor mount | Analog key-position sensing |
| Kapton sensor cover | Directly above Hall sensor | 2 layers, `50-100 um` each | Fixed | Electrical and mechanical isolation of the sensor face |
| Front end-stop felt | `15 mm` longitudinal contact zone in front sensor region | `2.0 mm` felt | Fixed | First tactile strike point and end damping |
| Felt support under PORON | Continues below rear compression zone | `2.0 mm` felt base | Fixed | Continuous substrate for PORON and direct material transition |
| PORON aftertouch zone | Behind front end stop, before guide pin | `4.0 mm` PORON recessed by `2.0 mm` | Fixed | Controlled aftertouch compression after first stop |
| PORON top level | Same rear zone as above | Flush with felt top because of `2.0 mm` recess over `2.0 mm` felt base | Fixed | Step-free transition from first stop into aftertouch zone |
| Front guide pin | `y = 60 mm` target | open | Fixed in `y` | Guidance after sensor and damping zones |
| Sensor-to-guide clearance | Hall sensor center to guide pin | minimum `25 mm` | Fixed | Magnetic and packaging clearance |

Target feel:

- Clear tactile strike point at first felt contact.
- Additional controlled aftertouch travel of about 2 mm to hard endpoint.

### 3.5 Interim Result (May 2026): VT Mechanics, Pivot Geometry, and Guidance

This section captures the current interim design state from recent geometry and mechanics discussions.

#### Main/VT Pivot Architecture (Interim)

- Main-key pivot target geometry follows piano-like proportions:
	- pivot axis about 24 mm below key top surface
	- pivot position about 210 mm behind the front edge
- Main-key pivot region may use a local Tough Resin bearing bushing with about `5 mm` wall thickness where the shaft geometry needs more material and larger radii.
- Main keys are expected to move downward in the rear section to create vertical space for VT mechanics.
- VT pivot should not be placed directly above main-key pivot (stack height and collision risk become too high).
- Current VT key-body assumption: the VT lever can remain around `13 x 20 mm` in the main load-bearing zone, but may grow locally to about `22 mm` total height at the VT pivot region to provide more material for the bearing block and smooth transitions.
- Current support split:
	- main-key pivot: simpler mounted/on-top support is preferred
	- VT pivot: custom hybrid support is preferred only here, because the VT pivot region is the actual packaging bottleneck
- Current VT pivot support stack, from top to bottom:
	- Tough Resin bearing geometry
	- Tough Resin bearing bushing / local shaft insert in the VT pivot block
	- FDM coupling structure
	- aluminium U-profile
	- wood spacer strip
	- steel strap as lower stiffening belt
- Updated structural direction for the pivot carrier: a directly coupled lower square tube is acceptable and currently preferred over a larger spaced secondary frame, provided the whole assembly works as one stiff pivot frame.
- Current preferred practical frame concept:
	- aluminium U-profile carries the exchangeable Tough Resin shaft holders / fins
	- a steel square tube may sit directly below the aluminium profile as the main lower stiffener
	- both members should be screwed/clamped so they act as one structural pivot frame, not as two loosely coupled rails
- Return-spring load-path rule: spring reaction forces must be introduced into the same structural pivot frame that carries the pivot shafts.
- Do not anchor the springs against a decoupled auxiliary frame, because any relative compliance between spring frame and pivot frame would change the effective key feel and unnecessarily load the chassis.
- Consequence for detailed design: spring anchors may sit on the lower square tube only if that square tube is rigidly coupled to the pivot carrier and therefore belongs to the same structural frame reference.
- Anti-slip / service rule for the exchangeable Tough Resin holders: use geometric interlock into the aluminium U-profile (for example about `2 mm` penetration plus serration / tooth pattern against longitudinal slip), but avoid permanent bonding so worn holders remain replaceable.

#### Required CAD Method (TurboCAD)

- Build two envelope studies before final key solids:
	- side-view volume envelope (all end positions, collisions, support clearances)
	- top-view volume envelope (key spacing, supports, side clearances)
- Reserve support space at pivot blocks: **5 mm per side per octave**.
- Final key geometry is the intersection of side/top envelopes.

#### Guidance Strategy (Interim)

- Primary guidance concept: **central guide rib (Kimme)** in key/tas pocket pair.
- Side spacers at pivot are downgraded to secondary/backup role.
- With around 1.0 mm key-to-key gap, dedicated inter-key spacers are not practical.
- Nominal spacing targets:
	- visible key gap: ~1.0 mm
	- complex motion clearances near pivots/turning zones: 1.5-2.0 mm

#### Bearing/Contact Pairing (Interim)

- Guide noses around the 4 mm brass shaft are planned in **Tough Resin**.
- Current geometry target for the guide nose is about `3 mm` height and `3 mm` thickness, with generous radii so the local resin detail is not left as a thin sharp fin.
- VT pivot block should use a dedicated **Tough Resin bearing bushing** so the precise local shaft geometry is carried by a replaceable SLA insert rather than by the full FDM key body.
- Same design rule can also be used for the main-key pivot when local geometry benefits from a dedicated resin insert; current target wall thickness for these pivot bushings is about `5 mm`.
- Key-side bearing seat in ASA is planned as a non-binding contact arc (~160 deg seat geometry).
- Brass shaft must not be clamped under resin preload.
- Slots/grooves for shaft guidance should allow slight movement; target condition is “just freely rotatable shaft.”
- The bearing bushing is a geometry carrier only, not a preload element; the shaft must remain freely rotatable after full assembly.
- Practical fit rule for the Tough Resin bushing on the `4.0 mm` brass shaft: do not aim for line-to-line fit. Start with about `0.06-0.12 mm` diametral running clearance (roughly `4.06-4.12 mm` finished bore), then trim by test print / reaming if the actual resin process runs tighter or looser.

#### Tribology and Wear Philosophy

- Avoid ASA-on-ASA as primary sliding pair in critical guidance.
- Preferred pairing: ASA contact region against brass shaft, lubricated with a thin Silbergleit film.
- Keep lubrication minimal; no paste buildup in pockets.

#### Manufacturing Consequence

- Keys may be split into sub-parts for load-path-oriented print orientation and stronger joints.
- This is preferred over one-piece support-heavy prints when structural anisotropy would weaken pivot regions.

#### Next Verification Steps

- Check four collision end states in CAD (main up/down, VT up/down).
- Verify free shaft rotation after assembly (empty and fully built).
- Validate no hard rubbing in complex turning regions under full travel.

---

## Phase 4: Firmware

### 4.1 Development Environment

Decided: VS Code + PlatformIO (Teensy 4.1 / Teensyduino).

### 4.2 MIDI Protocol

Decided: 24-tone mapping, no MPE. See `Research.md` Section 3.

### 4.3 Velocity Algorithm

Basic principle with continuous Hall sensor:
```
t1 = time when signal crosses upper threshold (key moving)
t2 = time when signal crosses lower threshold (key struck)
dt = t2 - t1
velocity = f(1 / dt)   // inverse: small dt = hard strike
```
Calibration: mapping dt → MIDI Velocity (0–127) via lookup table or curve fitting.

### 4.4 Scan Loop

Requirements:
- Scan cycle time < 1 ms (for timing accuracy ≥ ±0.5 ms → velocity error < 5%)
- Timer-driven polling; no interrupt required for Hall sensors (analog level polling)

### 4.5 Multi-Processor Architecture (Current Preferred Direction)

- **Teensy 4.1** remains the real-time sensor front-end.
	- scans all Hall channels
	- calculates velocity and aftertouch-relevant real-time events
	- applies stored calibration locally
	- should stay independent from high-level protocol and UI load
- **ESP32** is the currently preferred system / control processor.
	- reads expressions, pedals, wheels, buttons, and other slow controls
	- orchestrates calibration sequences
	- can already emit standalone MIDI / MPE if the Raspberry Pi layer is omitted
	- stores and manages system settings
- **Raspberry Pi** becomes an optional higher-level back-end.
	- MIDI / MPE / OSC translation
	- optional SuperCollider host and audio engine
	- optional DAW-independent instrument stage

### 4.6 Internal Communication Split (Interim)

- Current preferred logical split:
	- Teensy -> ESP32 push-style event/data stream over UART
	- ESP32 -> Teensy control/calibration path may use SPI or an equivalent dedicated command channel
- Architectural rule: Teensy must remain autonomous in the scan loop and must not depend on polling by the ESP32.
- Parameter updates from the control side should become active only at safe synchronization points.

### 4.7 Slow Controllers / Expressions (Interim)

- `2-4` expression / pedal / wheel channels are currently expected.
- Preferred approach: measure them on the second controller, not on the Teensy real-time front-end.
- Best-quality path: second controller plus dedicated external ADC.
- Practical recommendation for the first stable build:
	- ESP32 for logic / control
	- external ADC such as `MCP3204` / `MCP3208` for expression channels
	- `10 kOhm` linear pots / pedals as preferred source impedance
	- RC filtering and software calibration / hysteresis on the control side

---

## Phase 5: Mechanical Series Production

### 5.1 Keys

*Follows after mock-up sign-off.*

- FDM print: Polymaker PolyLite ASA, printed upright
- Post-processing: sanding of bearing surfaces, press-fit inserts for lead weights
- SLA: frame modules, bearing blocks, aftertouch buffers

### 5.2 Keyboard Frame

*To follow.*

- Aluminium square tube 10×10×1 mm as structural member
- ASA node connectors with internal knurling, M4 heat-set inserts, epoxy bond
- Half-octave SLA Tough Resin modules with integral pivot web and partition walls

### 5.3 Print Files

*Paths to STL/STEP files will be linked here once available.*

---

## Phase 6: Electronics Final Version

*Follows after prototype validation.*

- PCB layout (KiCad or similar)
- Assembly drawing
- Manufacturing files

---

## Phase 7: Integration & Housing

### 7.1 Housing Concept

- Wooden corpus, stage-suitable
- Dimensions: width per key count, depth ≤ 350 mm, height ≤ 120 mm
- Control panel: pitchbend wheel, volume slider, optional octave-shift buttons
- Connectors: USB-C, 5-pin DIN MIDI Out, optional pedal socket (sustain)

### 7.2 Surface & Appearance

*To be discussed with the pianist.*

#### Post-Prototype Surface Strategy (Future Decision)

This is intentionally not part of the first prototype build. It records the current preferred direction for a later, more finished instrument state.

- VT key levers: ASA structural bodies, currently dimensioned around `13 x 20 mm` box section in the main load-bearing region, with lower front height where geometry permits.
- Functional guide / pivot inserts: SLA Tough Resin remains preferred for locally stressed bearing and guide details.
- Visible playing surfaces: ABS-like SLA resin remains acceptable as a later finish material because tactile feel is good and expected functional service life is likely much longer than purely cosmetic life.
- Current assumption for playing surfaces: optical ageing (gloss, yellowing, wear marks) is expected earlier than play-impairing failure; service life before functionally relevant replacement is expected to be in the `>15 years` range if the resin surface is well supported by the ASA substrate and does not carry the primary structural bending load.

#### Future Bonding Strategy for Playing Surfaces

- Later, finished instruments may use full-surface bonding of SLA playing surfaces to the ASA key body with a high-strength epoxy such as `UHU Endfest`.
- Do not rely on the adhesive to define alignment. The ASA carrier should still provide geometric seating and full-area support.
- Prepare both bonding faces by sanding and degreasing before bonding.
- Keep a thin continuous adhesive layer; do not squeeze the joint dry.
- UV protective clear coat is currently not planned for the actual playing surfaces, because finger abrasion would likely make the visual result worse before it provides meaningful lifetime benefit.

#### Prototype Boundary

- The first prototype does not need removable surface parts.
- The first prototype does not need final visual surface finishing.
- The notes above are kept only as a documented later-stage option.

---

## Phase 8: Test & Calibration

*To follow.*

- Guided service calibration per key should use three points:
	- `0` = rest position
	- `pressed` = user-defined weighted press point
	- `aftertouch` = defined aftertouch / end-zone point
- ESP32 should guide and store the calibration process; Teensy should measure and maintain the low-level sensor model.
- Optional slow zero-drift correction in true rest state is acceptable.
- Full in-play re-learning of `pressed` and `aftertouch` points is currently not desired.
- Velocity calibration: comparison with reference keyboard
- Latency measurement (target: < 5 ms)
- Stage test: stage suitability, handling, transport

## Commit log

2026-07-05 Added STP files
    [A_SteelPins.stp, Buffer_V0.stp, KeyEndSTop.stp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]
2026-07-05 Some drawings reorganized
    [Buffer_V0.stp, KeyEndSTop.stp, KeysLong.stp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]
2026-07-10 Hall Senosr Cross Talk
2026-07-25 first FreeCAD tests
    [Buffer_V0.stp, KeyEndSTop.stp, KeysLong.stp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]
2026-07-25 Update Parameter Management
    [Klak20.FCStd, Washers.FCStd]
2026-07-28 Klak20 with rounded nut edges in the sketch.
    [Klak20.FCStd]
2026-08-02 Offset added
    [Klak20.FCStd]
2026-08-02 new bought parts
    [Nuts.FCStd, Test.FCStd, Washers.FCStd]
2026-08-02 first sliders
    [Klak20_Slider_Bolted.FCStd, Klak20_Slider_Bolted_No_Washers.FCStd]
2026-08-03 Washers as Flags
    [Klak20_Slider_Bolted.FCStd, Klak20_Slider_Bolted_No_Washers.FCStd, Klak20_Slider_Bonded.FCStd]
2026-08-03 sliders finished
    [Klak20_Slider_Bolted.FCStd, Klak20_Slider_Bonded.FCStd]
2026-08-04 Klak20 slider dev. finished
    [Klak20_Slider_Bolted.FCStd]
2026-08-05 keys dimensioning (intermidiate 1)
    [Keys.FCStd]
2026-08-07 interim save
    [Keys.FCStd, KeysPreview.FCStd]
2026-08-07 pre Split
    [Keys.FCStd, KeysPreview.FCStd]
2026-08-08 first complete keys-layout in FeeCAD
    [Keys.FCStd, KeysPreview.FCStd, MasterLayout.csv]
2026-08-09 FIles moved
    [Keys.FCStd, KeysPreview.FCStd, Klak20.FCStd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]
2026-08-09 reorganistaion finished
    [Globals.csv, Keys.FCStd, KeysLayout.csv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]
2026-08-10 corrected the klak20 sliders and mounts
    [Keys.FCStd, KeysPreview.FCStd, Klak20.FCStd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]
2026-08-11 interim status
    [Keys.FCStd, KeysPreview.FCStd, Klak20.FCStd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]
2026-08-12 pre pivot axis
    [Keys.FCStd, KeysPreview.FCStd, MainModel.FCStd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]
2026-08-12 pivor axis mount body
    [Keys.FCStd, KeysPreview.FCStd, Klak20_Slider_Bonded.FCStd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]
2026-08-12 complete pivot and zero stop design
    [Globals.csv, Keys.FCStd, KeysPreview.FCStd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]
2026-08-13 FInished Rear Lever YZ Design
    [Keys.FCStd, KeysPreview.FCStd, Klak20.FCStd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]
2026-08-13 last checks after merge
    [Keys.FCStd, KeysPreview.FCStd, LeverBearingYZ.FCStd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]
2026-08-13 some reorgs
    [Keys.FCStd, KeysPreview.FCStd, LeverRearYZ.FCStd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]
2026-08-13 bottom slope for QTs
    [Keys.FCStd, KeysPreview.FCStd]
2026-08-13 moved KeysPreview to assemblies
    [Keys.FCStd, KeysPreview.FCStd, MainModel.FCStd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]
2026-08-17 Ready to merge
    [Keys.FCStd, KeysPreview.FCStd, LeverRearYZ.FCStd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]
2026-08-22 Intermediate Version
    [Keys.FCStd, KeysPreview.FCStd, LeverRearYZ.FCStd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]
2026-08-22 Intermdiate Version working
    [Keys.FCStd, KeysPreview.FCStd, LeverRearYZ.FCStd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]
2026-08-30 Changes in Reaction Group Geometry and Concept.
    [KeysPreview.FCStd, MainModel.FCStd, Master.FCStd]
2026-09-07 ReactionGroup YZ-BuildingBlocks
    [LeversFrontYZ.FCStd, Master.FCStd, ReactionGroups.FCStd]
2026-09-12 tKeyLayout Reorganized
    [Keys.FCStd, Master.FCStd]
2026-09-13 Tables reorganized
    [Keys.FCStd, KeysPreview.FCStd, LeverRearYZ.FCStd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]
2026-09-19 Complete reaction-group YZ CAD work
    [KeysPreview.FCStd, LeverRearYZ.FCStd, LeversFrontYZ.FCStd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]
2026-10-04 Splint position verified
    [Keys.FCStd, KeysPreview.FCStd, Klak20.FCStd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]
2026-10-06 Complete zero-stop key guidance
    [Keys.FCStd, KeysPreview.FCStd, Klak20.FCStd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]
2026-10-18 lever return spring anchors finished
2026-10-26 return spring anchors fixed
2026-11-14 Finalize aftertouch stamp CAD updates
